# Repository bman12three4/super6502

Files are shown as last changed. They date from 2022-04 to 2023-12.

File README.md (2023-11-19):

# Super6502

## Overview

Super6502 is a microcomputer system powered by a 65C02 CPU. The goal of this
project is to create a computer system with modern features and the ability to
run modern software on an unmodified 65C02 core. While the project is almost
entirely contained in an FPGA, this rule is enforced by using an off the shelf
CPU.

## Goals

There are a few goals that I have for this project.

The number 1 goal is to create a pre-emptive multitasking operating system with
virtual memory.

I also have a few stretch goals:

1. Connect it to the internet

2. Boot linux (lol)

Along the way, there are a few milestones that I want to reach:

* USB support, including mass storage and peripherals
* HDMI Display output
* Ethernet

## Details

Currently, the project is built around an Efinix Trion T20F256 Development board.
I also have a breakout board with an SD card slot, a MAX3421E, and an audio codec
(that I forget the pn) which I got at school. Right now I only use the SD card.

The development board is sparse, but it includes SDRAM and enough headers to add
any other peripherals.

I designed a board to plug into one of the headers which exposes nearly all the pins
of a 65C02 directly to the FPGA, with no external circuitry except for 2 pull-up
resistors.

The heart of the project is `super6502.sv`. This file contains all of the various
parts of the project. It contains a small boot rom, but the rest of the code is
loaded from an SD card. All of the peripherals are also instantiated here, and there
is a block at the top for address decoding. It currently contains a very simple MMU
which allows the CPU access to the full 32MB address space. Other peripherals include
a timer, leds, hardware multiplier and divider, a uart, an spi controller (for the sd
card), an interrupt controller, and the SDRAM controller.

The SDRAM controller is the one supplied by the FPGA manufacturer, efinix, but contained
in a wrapper which adapts the native bus to the 6502 bus.

One aspect of the project that I want to improve on is bus interoperability. There is
a huge world of IP that is available if I support AXI or WishBone, but at the moment
I do not.

## Simulation Effort

Because I mostly work on this project while on the bus going to/from work, I can't be
iteratively testing on the hardware. I was inspired by the simulation setup we have at
work for the Starlink ASICs and decided to try and implement something similar, albeit
with only free tools at my disposal. It mostly works, but is very slow. Booting the
kernel takes nearly an hour(!), and that is with no kernel features or functionality.

For this reason, the IP blocks have standalone simulations as well as full system
simulations

## Contributing

While I appreciate feedback, this my own personal project and I will not accept
external contributions.

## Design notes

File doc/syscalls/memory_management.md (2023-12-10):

# Physical Memory Management

Physical memory will be handled in 4kb chunks. Each of these chunks needs to
be managed somehow.

We need a way for each PID to correspond with a list of memory mappings that
need to be loaded in.

In the ultra simple case. We don't assign memory dynamically and the mappings
are completely dependent on the PID. This is the easy case, allows only for
1022 processes at once.

The physical memory mapping then depends on the PID, where the base address of
any process is $$ (PID + 1) * 65536 $$

For minimum proof of concept, we can roll with this for now.

In the future, I would only like to assign a minimum of 8 blocks to a process,
and any dynamically allocated blocks would come after that.



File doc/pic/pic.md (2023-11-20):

# PIC

## Overview

The PIC (Programmable Interrupt Controller) supports 256 edge or level
triggered interrupts.

Interrupts can only be rising edge or positive level trigger. Negative edge or
low level trigger can be accomplished by inverting the input to this module.

When an interrupt is triggered, it remains triggered until cleared with an
`EOI`. Currently, only the highest priority interrupt can be cleared. This
is bad design and will be fixed soon(tm).

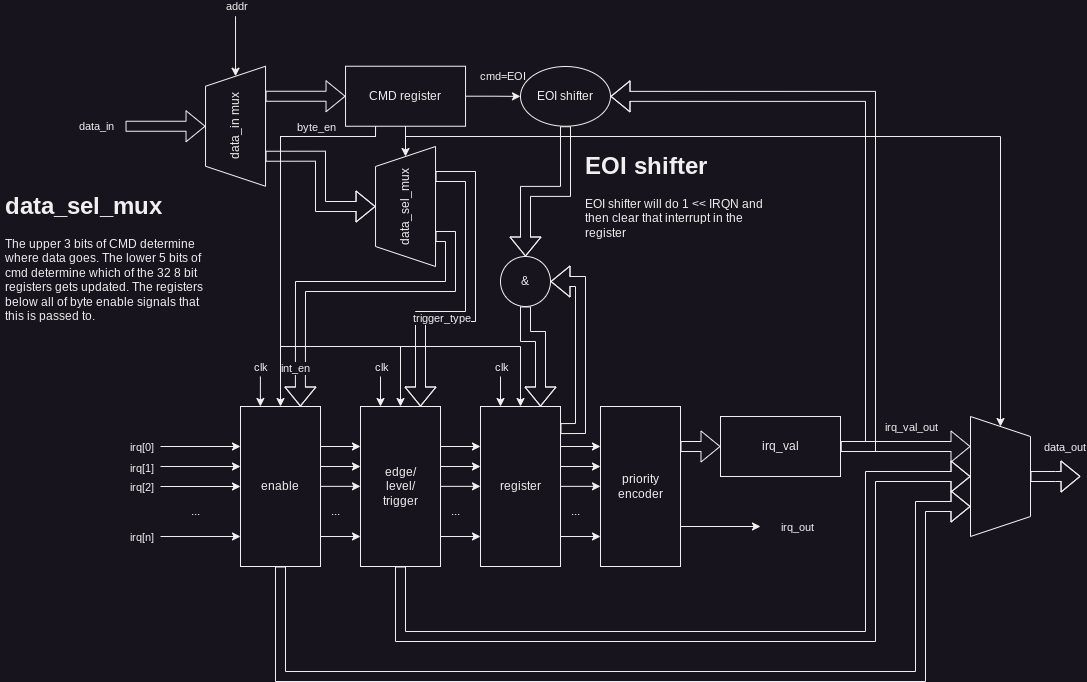
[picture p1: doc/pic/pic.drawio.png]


## Interface

The PIC is controlled through two 8-bit registers, `CMD` and `DAT`.
The upepr 3 bits of `CMD` control which register is accessed, and the lower 5
bits control the byte select.

`EOI` is a special case: when `CMD` is 0xFF, the highest priority interrupt is
cleared.

### CMD
| [7:5] 	| [4:0] 	|
|---	|---	|
| Register Address 	| Byte Select 	|

### DAT
| [7:0]                 	|
|-----------------------	|
| Data[8*Byte_sel +: 8] 	|

## Registers

### Register Map

| Address 	| Read 	| Write  	|
|---	|---	|---	|
| 0 	| IRQ Number 	| ~ 	|
| 1 	| Enable 	| Enable 	|
| 2 	| Type 	| Type 	|

### IRQ Number

8 bit register outputs the highest priority interrupt currently active. When 
no interrupt is active, it will output 255.

### Enable

256 bit enable register. When bit _n_ is set to 1, the corresponding interrupt
_n_.

### Type

256 bit type register. When bit _n_ is set to 0, the corresponding interrupt
_n_ will be edge triggered. If the bit is set to 1, the interrupt will be level
triggered.

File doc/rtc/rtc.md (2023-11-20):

# RTC

## Overview

The RTC is capable of keeping track of elapsed time as well as generating
periodic interrupts. Its input frequency is (currently) the same as the CPU
frequency. The architecture is shown below:

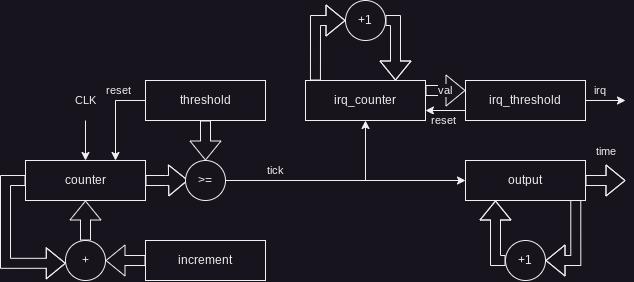
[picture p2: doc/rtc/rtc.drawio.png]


The `counter` register is a 32 bit register which increments by `increment`
every clock tick. When this value reaches `threshold`, both `output` and
`irq_counter` are incremented by 1. When `irq_counter` reaches `irq_threshold`,
an interrupt is generated.

The interrupt frequency can be calculated with the following equations:

$$ F_{out}=\frac{F_{in}\cdot{increment}}{threshold} $$
$$ F_{irq}=\frac{F_{out}}{irq\_threshold} $$

Where $ F_{out} $ is the frequency at which the output changes and $ F_{irq} $
is the frequency at which interrupts occur.

## Interface

The RTC is controlled through two 8-bit registers, `CMD` and `DAT`.
The upepr 4 bits of `CMD` control which register is accessed, and the lower 4
bits control the byte select. The RTC uses 32 bit registers, so only values of
0-3 are supported.

### CMD
| [7:4] 	| [3:2 	| [1:0] 	|
|---	|---	|---	|
| Register Address 	| Reserved 	| Byte Select 	|

### DAT
| [7:0]                 	|
|-----------------------	|
| Data[8*Byte_sel +: 8] 	|

## Registers

### Register Map

| Address 	| Read 	| Write 	|
|---	|---	|---	|
| 0 	| Threshold 	| Threshold 	|
| 1 	| Increment 	| Increment 	|
| 2 	| IRQ Threshold 	| IRQ Threshold 	|
| 3 	| Output 	| Control 	|

### Threshold

32 bit threshold register. When `counter` reaches this value, `output` and
`irq_counter` are incremented by 1, and `counter` is reset back to 0.

### Increment

32 bit increment register. Every clock cycle, `counter` is incremented by
`increment`

### IRQ Threshold

32 bit IRQ threshold register. When `irq_counter` reaches this value, and IRQ
is generated and `irq_counter` is reset back to 0.

### Output

32 bit output register. This value ticks up.

### Control

| [7:2] 	| [1] 	| [0] 	|
|---	|---	|---	|
| Reserved 	| IRQ Enable 	| Enable 	|

8 bit Control register. Regardless of Byte Select, any write to address 3 will
write to this register. `IRQ Enable` controls interrupt generation. `Enable` is
a global enable. When 0, all counter registers are set to 0.

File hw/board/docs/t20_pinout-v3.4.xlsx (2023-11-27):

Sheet: T20F169
© 2020 |  | v23
Bank Number | Pin Names | Configuration Functions | MIPI Channels | LVDS TX/RX Pairs | DDIO | FBGA169
- | GND |  |  |  |  | A1
- | GND |  |  |  |  | A13
- | GND |  |  |  |  | E12
- | GND |  |  |  |  | E2 | Legend
- | GND |  |  |  |  | F5 |  | Bank 1A pins
- | GND |  |  |  |  | F6 |  | Bank 1B pins
- | GND |  |  |  |  | F8 |  | Bank 1C pins
- | GND |  |  |  |  | G6 |  | Bank 1D pins
- | GND |  |  |  |  | G7 |  | Bank 1E pins
- | GND |  |  |  |  | J7 |  | Bank 3A pins
- | GND |  |  |  |  | J8 |  | Bank 3B pins
- | GND |  |  |  |  | K12 |  | Bank 3C pins
- | GND |  |  |  |  | K2 |  | Bank 3D pins
- | GND |  |  |  |  | L12 |  | Bank 3E pins
- | GND |  |  |  |  | M4 |  | Bank 4A pins
- | GND |  |  |  |  | N1 |  | Bank 4B pins
- | GND |  |  |  |  | N13
- | GNDA_MIPI |  |  |  |  | C11
- | GNDA_MIPI |  |  |  |  | D11 | Note: | In the Legend, banks with the same color have their power shorted in the package
- | GNDA_MIPI |  |  |  |  | D3 |  | For example, VCCIO3C_3D_3E shorts the power of bank 3C, 3D and 3E together
- | GNDA_MIPI |  |  |  |  | E5
- | VCC |  |  |  |  | E4
- | VCC |  |  |  |  | F7
- | VCC |  |  |  |  | F9
- | VCC |  |  |  |  | G5
- | VCC |  |  |  |  | G8
- | VCC |  |  |  |  | G9
- | VCC |  |  |  |  | H6
- | VCC |  |  |  |  | J6
- | VCC12A_MIPI0_RX |  |  |  |  | E6
- | VCC12A_MIPI0_TX |  |  |  |  | C3
- | VCC12A_MIPI1_RX |  |  |  |  | E10
- | VCC12A_MIPI1_TX |  |  |  |  | E8
- | VCC25A_MIPI0 |  |  |  |  | E7
- | VCC25A_MIPI1 |  |  |  |  | E9
- | VCCA_BR |  |  |  |  | J10
- | VCCA_TL |  |  |  |  | G4
- | VCCA_TR |  |  |  |  | G10
- | VCCIO1A |  |  |  |  | J4
- | VCCIO1B_1C_1D |  |  |  |  | H4
- | VCCIO1E |  |  |  |  | F4
- | VCCIO3A_3B |  |  |  |  | F10
- | VCCIO3C_3D_3E |  |  |  |  | H10
- | VCCIO4A |  |  |  |  | H7
- | VCCIO4A |  |  |  |  | H8
- | VCCIO4A |  |  |  |  | H9
- | VCCIO4A |  |  |  |  | J9
- | VCCIO4B |  |  |  |  | H5
- | VCCIO4B |  |  |  |  | J5
BANK1A | CDONE | CDONE |  |  |  | L2
BANK1A | CRESET_N | CRESET_N |  |  |  | K3
BANK1A | GPIOL_00_SS_N | SS_N |  |  |  | L1
BANK1A | GPIOL_01_CCK | CCK |  |  |  | K1
BANK1A | GPIOL_08_CDI0 | CDI0 |  |  |  | J1
BANK1A | GPIOL_09_CDI1 | CDI1 |  |  |  | J2
BANK1A | TCK |  |  |  |  | H1
BANK1A | TDI |  |  |  |  | J3
BANK1A | TDO |  |  |  |  | G1
BANK1A | TMS |  |  |  |  | H2
BANK1B | GPIOL_12_CDI2 | CDI2 |  |  | Yes | F1
BANK1B | GPIOL_13_CDI3 | CDI3 |  |  | Yes | G2
BANK1B | GPIOL_20_CTRL0_CDI4 |  |  |  | Yes | E1
BANK1B | GPIOL_21_CTRL1_CDI5 |  |  |  | Yes | F2
BANK1B | GPIOL_24_CLK0 |  |  |  | Yes | H3
BANK1B | GPIOL_25_CLK1 |  |  |  | Yes | G3
BANK1E | GPIOL_69_CBSEL1 | CBSEL1 |  |  |  | D1
BANK1E | GPIOL_70_CBSEL0 | CBSEL0 |  |  |  | D2
BANK1E | GPIOL_71_NSTATUS | NSTATUS |  |  |  | C2
BANK1E | GPIOL_72_EXTFB0_CDI14 |  |  |  |  | F3
BANK1E | GPIOL_73_EXTFB1_CDI15 |  |  |  |  | C1
BANK1E | GPIOL_74_PLLIN0 |  |  |  |  | E3
BANK1E | GPIOL_75_PLLIN1 |  |  |  |  | B1
BANK2A | MIPI0_RXDN0 |  | MIPI_RX0 |  |  | A5
BANK2A | MIPI0_RXDN1 |  | MIPI_RX0 |  |  | D6
BANK2A | MIPI0_RXDN2 |  | MIPI_RX0 |  |  | A6
BANK2A | MIPI0_RXDN3 |  | MIPI_RX0 |  |  | D7
BANK2A | MIPI0_RXDN4 |  | MIPI_RX0 |  |  | A7
BANK2A | MIPI0_RXDP0 |  | MIPI_RX0 |  |  | B5
BANK2A | MIPI0_RXDP1 |  | MIPI_RX0 |  |  | C6
BANK2A | MIPI0_RXDP2 |  | MIPI_RX0 |  |  | B6
BANK2A | MIPI0_RXDP3 |  | MIPI_RX0 |  |  | C7
BANK2A | MIPI0_RXDP4 |  | MIPI_RX0 |  |  | B7
BANK2A | MIPI0_TXDN0 |  | MIPI_TX0 |  |  | B2
BANK2A | MIPI0_TXDN1 |  | MIPI_TX0 |  |  | D4
BANK2A | MIPI0_TXDN2 |  | MIPI_TX0 |  |  | B3
BANK2A | MIPI0_TXDN3 |  | MIPI_TX0 |  |  | D5
BANK2A | MIPI0_TXDN4 |  | MIPI_TX0 |  |  | B4
BANK2A | MIPI0_TXDP0 |  | MIPI_TX0 |  |  | A2
BANK2A | MIPI0_TXDP1 |  | MIPI_TX0 |  |  | C4
BANK2A | MIPI0_TXDP2 |  | MIPI_TX0 |  |  | A3
BANK2A | MIPI0_TXDP3 |  | MIPI_TX0 |  |  | C5
BANK2A | MIPI0_TXDP4 |  | MIPI_TX0 |  |  | A4
BANK2B | MIPI1_RXDN0 |  | MIPI_RX1 |  |  | A11
BANK2B | MIPI1_RXDN1 |  | MIPI_RX1 |  |  | D10
BANK2B | MIPI1_RXDN2 |  | MIPI_RX1 |  |  | A12
BANK2B | MIPI1_RXDN3 |  | MIPI_RX1 |  |  | D12
BANK2B | MIPI1_RXDN4 |  | MIPI_RX1 |  |  | B13
BANK2B | MIPI1_RXDP0 |  | MIPI_RX1 |  |  | B11
BANK2B | MIPI1_RXDP1 |  | MIPI_RX1 |  |  | C10
BANK2B | MIPI1_RXDP2 |  | MIPI_RX1 |  |  | B12
BANK2B | MIPI1_RXDP3 |  | MIPI_RX1 |  |  | C12
BANK2B | MIPI1_RXDP4 |  | MIPI_RX1 |  |  | C13
BANK2B | MIPI1_TXDN0 |  | MIPI_TX1 |  |  | A8
BANK2B | MIPI1_TXDN1 |  | MIPI_TX1 |  |  | D8
BANK2B | MIPI1_TXDN2 |  | MIPI_TX1 |  |  | B9
BANK2B | MIPI1_TXDN3 |  | MIPI_TX1 |  |  | D9
BANK2B | MIPI1_TXDN4 |  | MIPI_TX1 |  |  | B10
BANK2B | MIPI1_TXDP0 |  | MIPI_TX1 |  |  | B8
BANK2B | MIPI1_TXDP1 |  | MIPI_TX1 |  |  | C8
BANK2B | MIPI1_TXDP2 |  | MIPI_TX1 |  |  | A9
BANK2B | MIPI1_TXDP3 |  | MIPI_TX1 |  |  | C9
BANK2B | MIPI1_TXDP4 |  | MIPI_TX1 |  |  | A10
BANK3A | GPIOR_76_PLLIN0 |  |  |  |  | D13
BANK3A | GPIOR_77_PLLIN1 |  |  |  |  | F12
BANK3A | GPIOR_78_EXTFB0_CDI31 |  |  |  |  | E13
BANK3A | GPIOR_81_MREFCLK |  |  |  |  | F11
BANK3A | GPIOR_85 |  |  |  |  | E11
BANK3A | GPIOR_88_CDI28 |  |  |  |  | G11
BANK3C | GPIOR_119_CTRL12 |  |  |  | Yes | F13
BANK3C | GPIOR_120_CLK15 |  |  |  | Yes | G12
BANK3C | GPIOR_121_CLK14 |  |  |  | Yes | H11
BANK3E | GPIOR_150_CBUS1 | CBUS1 |  |  | Yes | G13
BANK3E | GPIOR_151_CBUS0 | CBUS0 |  |  | Yes | J11
BANK3E | GPIOR_155 |  |  |  | Yes | H13
BANK3E | GPIOR_157_PLLIN |  |  |  | Yes | J12
BANK3E | GPIOR_158_TEST_N | TEST_N |  |  | Yes | H12
BANK4A | GPIOB_CLKN0 |  |  | GPIOB_CLK0 |  | L13
BANK4A | GPIOB_CLKP0 |  |  | GPIOB_CLK0 |  | M13
BANK4A | GPIOB_RXN00 |  |  | GPIOB_RX00 |  | K7
BANK4A | GPIOB_RXN01 |  |  | GPIOB_RX01 |  | M7
BANK4A | GPIOB_RXN02 |  |  | GPIOB_RX02 |  | K8
BANK4A | GPIOB_RXN03 |  |  | GPIOB_RX03 |  | N8
BANK4A | GPIOB_RXN04 |  |  | GPIOB_RX04 |  | L9
BANK4A | GPIOB_RXN05 |  |  | GPIOB_RX05 |  | N9
BANK4A | GPIOB_RXN06 |  |  | GPIOB_RX06 |  | L10
BANK4A | GPIOB_RXN07 |  |  | GPIOB_RX07 |  | M10
BANK4A | GPIOB_RXN08 |  |  | GPIOB_RX08 |  | L11
BANK4A | GPIOB_RXN09 |  |  | GPIOB_RX09 |  | M12
BANK4A | GPIOB_RXN10 |  |  | GPIOB_RX10 |  | N12
BANK4A | GPIOB_RXN12_EXTFB0 |  |  | GPIOB_RX12 |  | K13
BANK4A | GPIOB_RXP00 |  |  | GPIOB_RX00 |  | L7
BANK4A | GPIOB_RXP01 |  |  | GPIOB_RX01 |  | N7
BANK4A | GPIOB_RXP02 |  |  | GPIOB_RX02 |  | L8
BANK4A | GPIOB_RXP03 |  |  | GPIOB_RX03 |  | M8
BANK4A | GPIOB_RXP04 |  |  | GPIOB_RX04 |  | K9
BANK4A | GPIOB_RXP05 |  |  | GPIOB_RX05 |  | M9
BANK4A | GPIOB_RXP06 |  |  | GPIOB_RX06 |  | K10
BANK4A | GPIOB_RXP07 |  |  | GPIOB_RX07 |  | N10
BANK4A | GPIOB_RXP08 |  |  | GPIOB_RX08 |  | K11
BANK4A | GPIOB_RXP09 |  |  | GPIOB_RX09 |  | M11
BANK4A | GPIOB_RXP10 |  |  | GPIOB_RX10 |  | N11
BANK4A | GPIOB_RXP12_EXTFB0 |  |  | GPIOB_RX12 |  | J13
BANK4B | GPIOB_TXN00 |  |  | GPIOB_TX00 |  | N2
BANK4B | GPIOB_TXN01 |  |  | GPIOB_TX01 |  | M1
BANK4B | GPIOB_TXN02 |  |  | GPIOB_TX02 |  | L3
BANK4B | GPIOB_TXN03 |  |  | GPIOB_TX03 |  | L4
BANK4B | GPIOB_TXN05 |  |  | GPIOB_TX05 |  | M5
BANK4B | GPIOB_TXN06 |  |  | GPIOB_TX06 |  | L5
BANK4B | GPIOB_TXN08 |  |  | GPIOB_TX08 |  | M6
BANK4B | GPIOB_TXN09 |  |  | GPIOB_TX09 |  | L6
BANK4B | GPIOB_TXP00 |  |  | GPIOB_TX00 |  | N3
BANK4B | GPIOB_TXP01 |  |  | GPIOB_TX01 |  | M2
BANK4B | GPIOB_TXP02 |  |  | GPIOB_TX02 |  | M3
BANK4B | GPIOB_TXP03 |  |  | GPIOB_TX03 |  | K4
BANK4B | GPIOB_TXP05 |  |  | GPIOB_TX05 |  | N5
BANK4B | GPIOB_TXP06 |  |  | GPIOB_TX06 |  | K5
BANK4B | GPIOB_TXP08 |  |  | GPIOB_TX08 |  | N6
BANK4B | GPIOB_TXP09 |  |  | GPIOB_TX09 |  | K6
BANK4B | REF_RES |  |  |  |  | N4
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

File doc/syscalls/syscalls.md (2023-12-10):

# Syscalls and Process Creation

## Creating a Process

This is a little bit simpler than on x86 since we don't have to worry about 
process rings and such.

1. Remap the program address space to somewhere new in memory
2. Load the o65 file into memory
3. Remap page zero
4. Jump into starting address of program

We also need to save address of the instruction after the jump. If I am not 
mistaken then this would always be the same anyway. Regardless, we can get
this address by using `jsr` if we want it to be dynamic.

The hardware and software stacks are hardcoded, but we can remap page zero
into a different page (say, page 1) to make the changes to the stack pointers
and such, and then only remap it right before we jump in.

Unfortunately this means we won't be able to use a funtion call for this
since the return address would not be where we expect it.

A more detailed process then:

1. Determine the new processes PID. This will be used to determine the addresses
for where the main memory is mapped.

2. Map An area of ram for page zero. Here will will initialize the kernel
and user stack pointers, as well as place the Process Control Block.

3. Map the main program area into memory and copy data into it

4. Get the return address of the program, which is the address of the 
instruction following the `jmp`. 

5. Remap page zero

6. Immediately after that (like, the very next instruction) `jmp` to the start
of the user program. (We don't use `jsr` because that will save to the wrong
stack).

## Ending A Process

To end a process, we remap the parent processes memory, then jump back to the
address before the `jmp`, as noted before.

## Syscalls

Syscalls require the following:

1. Enter kernel space through use of software interrupt (`brk`)

2. Map in the kernel memory. The kernel is too large to always be mapped, so
we unmap it when we enter user space and remap it when we enter kernel space.

3. Jump to the specific syscall routine in the kernel and do whatever it does

4. Remap the current process memory

5. Jump back into userspace.

A note on 2: While we can't have the entire kernel mapped at all times, we must
have at least part of it so that we can handle interrupts and memory remapping.

This will be the top page in the virtual address space, aka 0xF000 to 0xFFFF.
This must be mapped anyway because it is where the hardware interrupt vectors
are located.

One thing to note about this is that the cc65 runtime will most likely not be
located there, nor do we really want it to be. Because of this, we will not
be able to have any C code, not will we be able to use the runtime in
assembly.

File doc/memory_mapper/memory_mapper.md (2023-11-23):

# Memory Mapper

## Overview

The memory mapper gives expands the CPU's address space from 16 bits to 25.
It can be expanded to be 28 bits, but only 25 are needed to access all of
sdram.

Its architecture is show below:

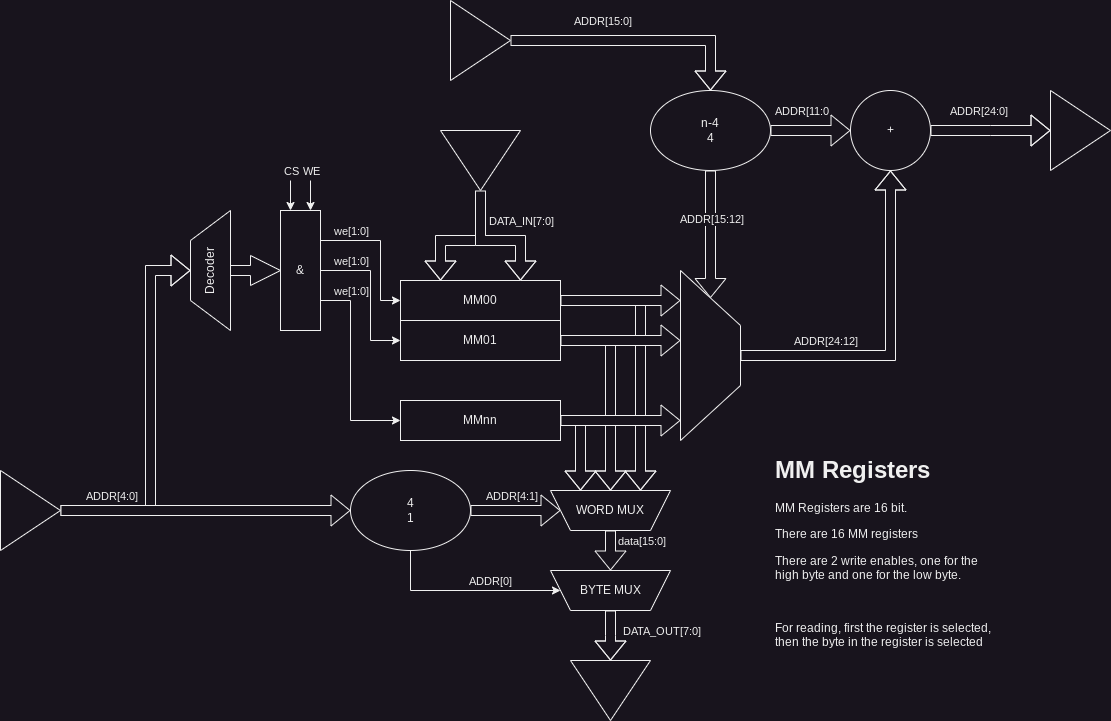
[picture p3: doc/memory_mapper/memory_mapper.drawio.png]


There are 32 16 bit registers: One for each 4k page in the virtual address
space. The memory mapper is always enabled, but at reset it is identity
mapped, i.e. register _n_ will be reset to value _n_.

## Interface

The Memory mapper is composed of 32 identical 16 bit mapping registers

The chip select should be calculated based on the virtual address. If not,
it will be possible for the CPU to map away access to the mapper, at which
point it is impossible to change the mappings without a reset.

## Registers

### Register Map

| Address 	| Read 	 | Write 	|
|---	|--- |---	|
| 00 	| MM0 Low 	| MM0 Low |
| 01 	| MM0 High  	| MM0 High |
| 02 	| MM1 Low 	| MM1 Low |
| 03 	| MM1 High  	| MM1 High |
| 04 	| MM2 Low 	| MM2 Low |
| 05 	| MM2 High  	| MM2 High |
| 06 	| MM3 Low 	| MM3 Low |
| 07 	| MM3 High  	| MM3 High |
| 08 	| MM4 Low 	| MM4 Low |
| 09 	| MM4 High  	| MM4 High |
| 0A 	| MM5 Low 	| MM5 Low |
| 0B 	| MM5 High  	| MM5 High |
| 0C 	| MM6 Low 	| MM6 Low |
| 0D 	| MM6 High  	| MM6 High |
| 0E 	| MM7 Low 	| MM7 Low |
| 0F 	| MM7 High  	| MM7 High |
| 10 	| MM8 Low 	| MM8 Low |
| 11 	| MM8 High  	| MM8 High |
| 12 	| MM9 Low 	| MM9 Low |
| 13 	| MM9 High  	| MM9 High |
| 14 	| MM10 Low  	| MM10 Low |
| 15 	| MM10 High 	| MM10 High |
| 16 	| MM11 Low  	| MM11 Low |
| 17 	| MM11 High 	| MM11 High |
| 18 	| MM12 Low  	| MM12 Low |
| 19 	| MM12 High 	| MM12 High |
| 1A 	| MM13 Low  	| MM13 Low |
| 1B 	| MM13 High 	| MM13 High |
| 1C 	| MM14 Low  	| MM14 Low |
| 1D 	| MM14 High 	| MM14 High |
| 1E 	| MM15 Low  	| MM15 Low |
| 1F 	| MM15 High 	| MM15 High |

### MMn Low

Low memory map data. Becomes bits [19:12] of physical address.

### MMn High

High memory map data. Becomes bits [27:20] of physical address.

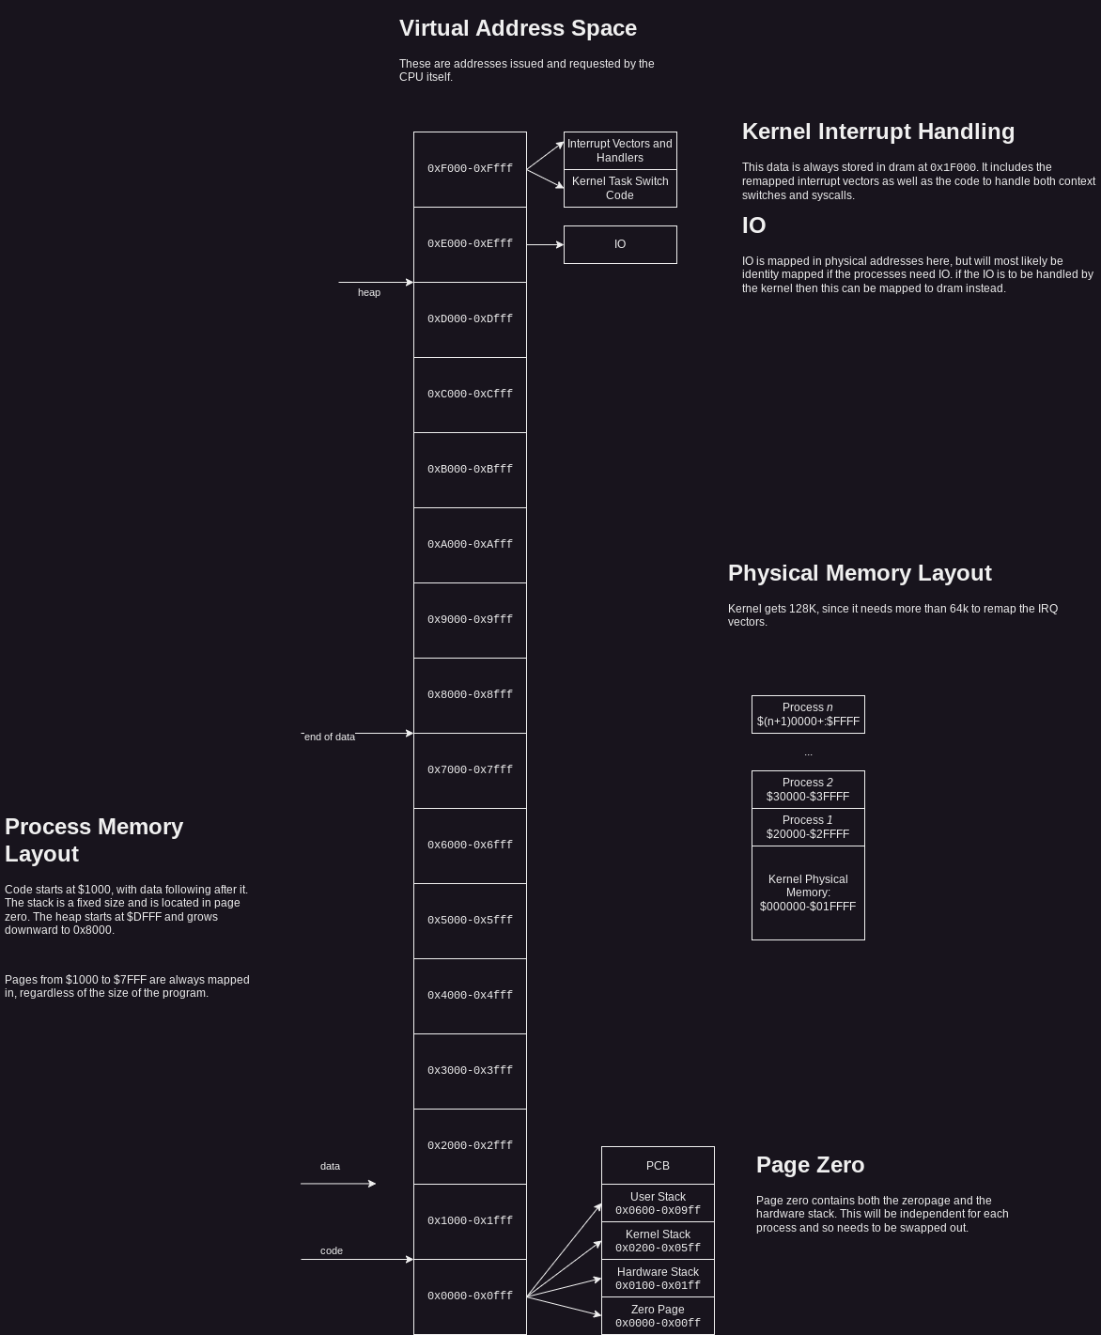
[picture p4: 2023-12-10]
doc/syscalls/Process_Layout.drawio.png

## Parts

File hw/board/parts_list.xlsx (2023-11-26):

Name | Part No | Price | Qty | Total | link | Note
FPGA | T20F400I4 | $26.96 | 1 | $26.96 | https://www.digikey.com/en/products/detail/efinix-inc/T20F400I4/15861249
DDR3L DRAM | MT41K256M8DA-125:K | $5.27 | 1 | $5.27 | https://www.digikey.com/en/products/detail/micron-technology-inc/MT41K256M8DA-125-K/3924859
SPI Flash | MX25V8035FM1I | $0.52 | 1 | $0.52 | https://www.digikey.com/en/products/detail/macronix/MX25V8035FM1I/5957748
MicroSD Card Slot | 5033981892 | $2.73 | 1 | $2.73 | https://www.digikey.com/en/products/detail/molex/5033981892/4555393
FTDI Adapter | FT4232HL-REEL | $6.35 | 1 | $6.35 | https://www.digikey.com/en/products/detail/ftdi-future-technology-devices-international-ltd/FT4232HL-REEL/1986055
USB C Connector | USB4085-GF-A | $0.94 | 1 | $0.94 | https://www.digikey.com/en/products/detail/gct/USB4085-GF-A/9859662
USB Host Controller | MAX3421EEHJ+ | $16.25 | 1 | $16.25 | https://www.digikey.com/en/products/detail/analog-devices-inc-maxim-integrated/MAX3421EEHJ/1464975
USB Hub | TUSB2046BVFR | $3.59 | 1 | $3.59 | https://www.digikey.com/en/products/detail/texas-instruments/TUSB2046BVFR/1910075
USB A Ports | 672984091 | $1.53 | 2 | $3.06 | https://www.digikey.com/en/products/detail/molex/0672984091/3598505
Ethernet PHY | KSZ8081MLXCA-TR | $1.64 | 1 | $1.64 | https://www.digikey.com/en/products/detail/microchip-technology/KSZ8081MLXCA-TR/3879220
Ethernet Jack | SI-50170-F | $5.38 | 1 | $5.38 | https://www.digikey.com/en/products/detail/bel-fuse-inc/SI-50170-F/1033369
HDMI Port | 10029449-111RLF | $1.26 | 1 | $1.26 | https://www.digikey.com/en/products/detail/amphenol-cs-fci/10029449-111RLF/2785386
VGA Port | ICD15S13E6GV00LF | $2.64 | 1 | $2.64 | https://www.digikey.com/en/products/detail/amphenol-cs-fci/ICD15S13E6GV00LF/1090326
6502 CPU | W65C02S6TPG-14 | $9.70 | 1 | $9.70 | https://www.mouser.com/ProductDetail/Western-Design-Center-WDC/W65C02S6TPG-14?qs=opBjA1TV903lvWo9AEKH5w%3D%3D | (Mouser but I already have some)
Green LED | LTST-C191KGKT | $0.06 | 100 | $6.30 | https://www.digikey.com/en/products/detail/liteon/LTST-C191KGKT/386835
3 Switch | 219-3MSTR | $0.69 | 1 | $0.69 | https://www.digikey.com/en/products/detail/cts-electrocomponents/219-3MSTR/5224026
8 Switch | 208-8 | $0.73 | 1 | $0.73 | https://www.digikey.com/en/products/detail/cts-electrocomponents/208-8/20795
Pushbutton | 1825910-6 | $0.13 | 4 | $0.52 | https://www.digikey.com/en/products/detail/te-connectivity-alcoswitch-switches/1825910-6/1632536
7 Segment | LTS-4802BJR-H1 | $1.28 | 6 | $7.68 | https://www.digikey.com/en/products/detail/liteon/LTS-4802BJR-H1/408200
Switching Regulator | ST1S40IDR | $2.18 | 4 | $8.72 | https://www.digikey.com/en/products/detail/stmicroelectronics/ST1S40IDR/3087736
Linear Regulator | ADP123AUJZ-R7 | $1.57 | 1 | $1.57 | https://www.digikey.com/en/products/detail/analog-devices-inc/ADP123AUJZ-R7/2237673
 |  |  |  | $112.50

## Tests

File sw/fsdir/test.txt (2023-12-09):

This is a text file, which is composed of text.

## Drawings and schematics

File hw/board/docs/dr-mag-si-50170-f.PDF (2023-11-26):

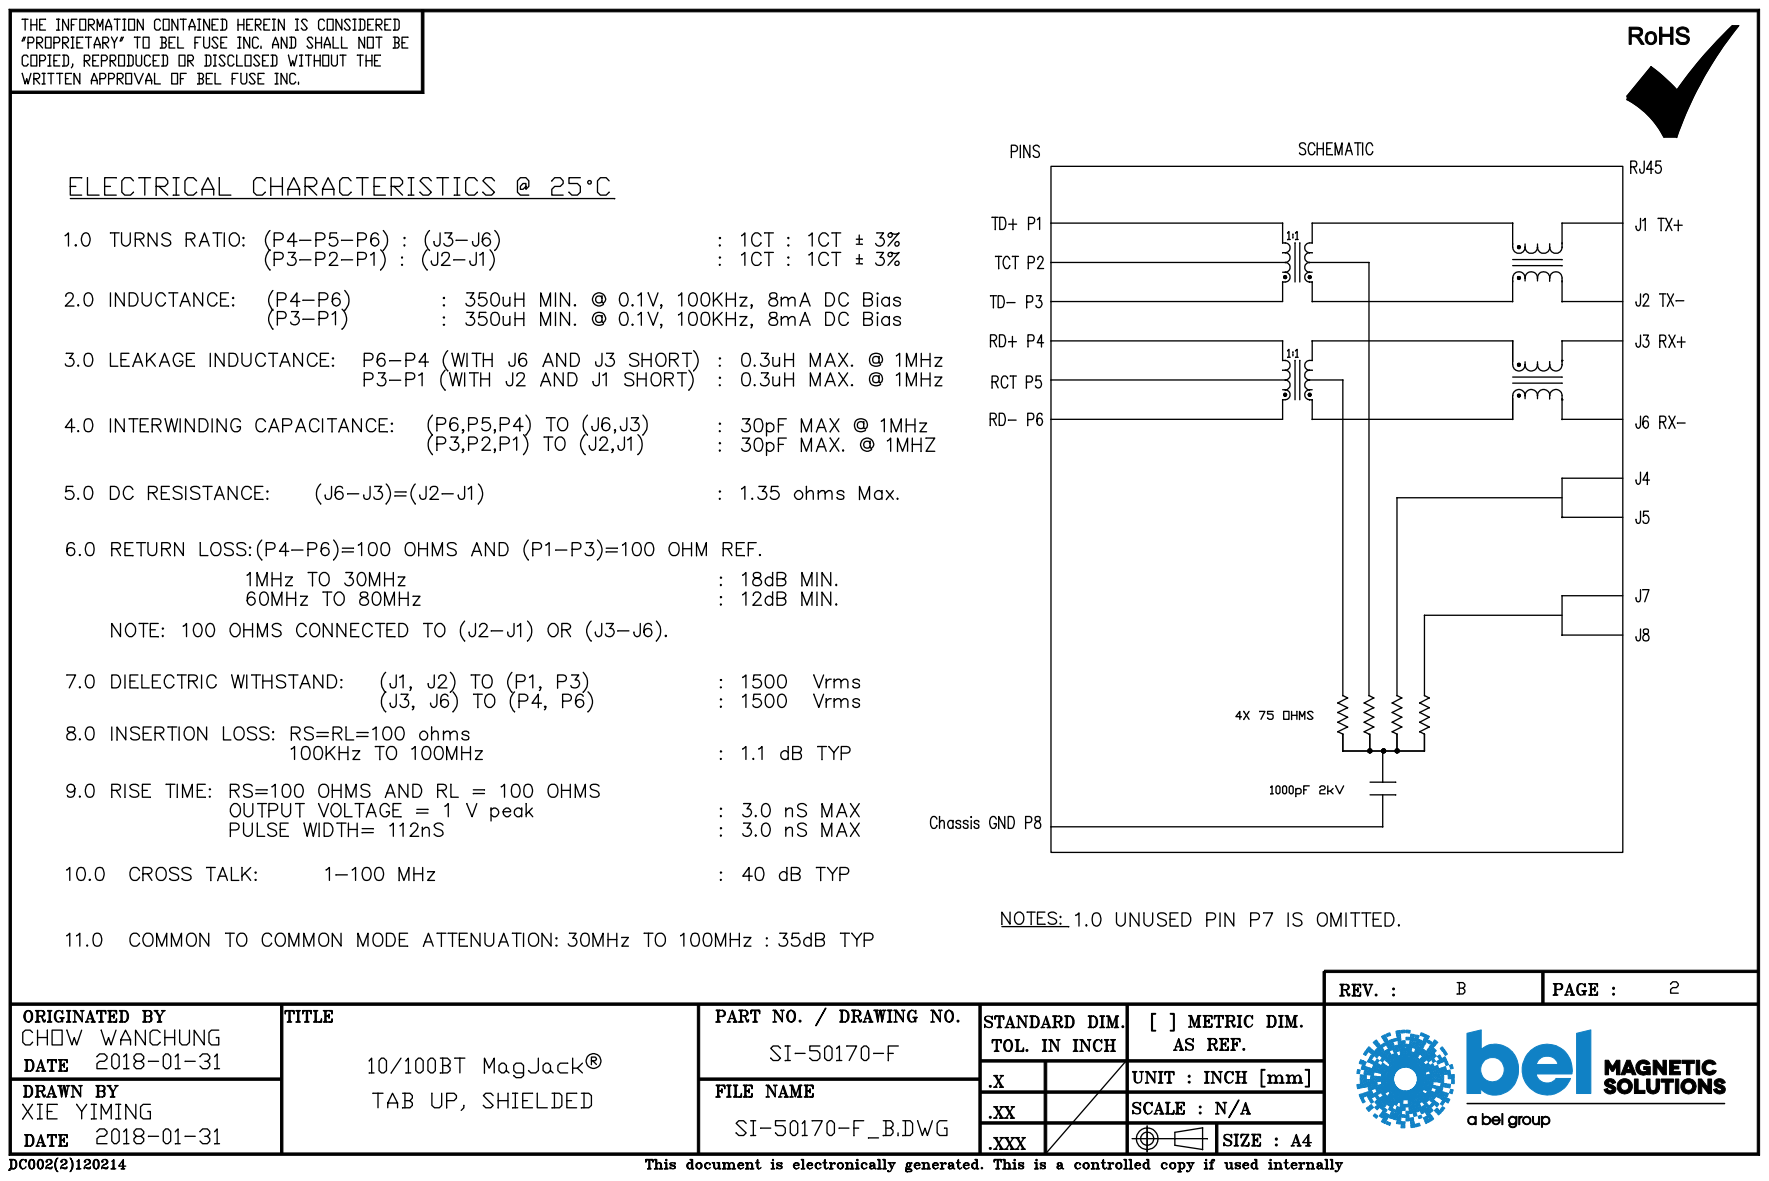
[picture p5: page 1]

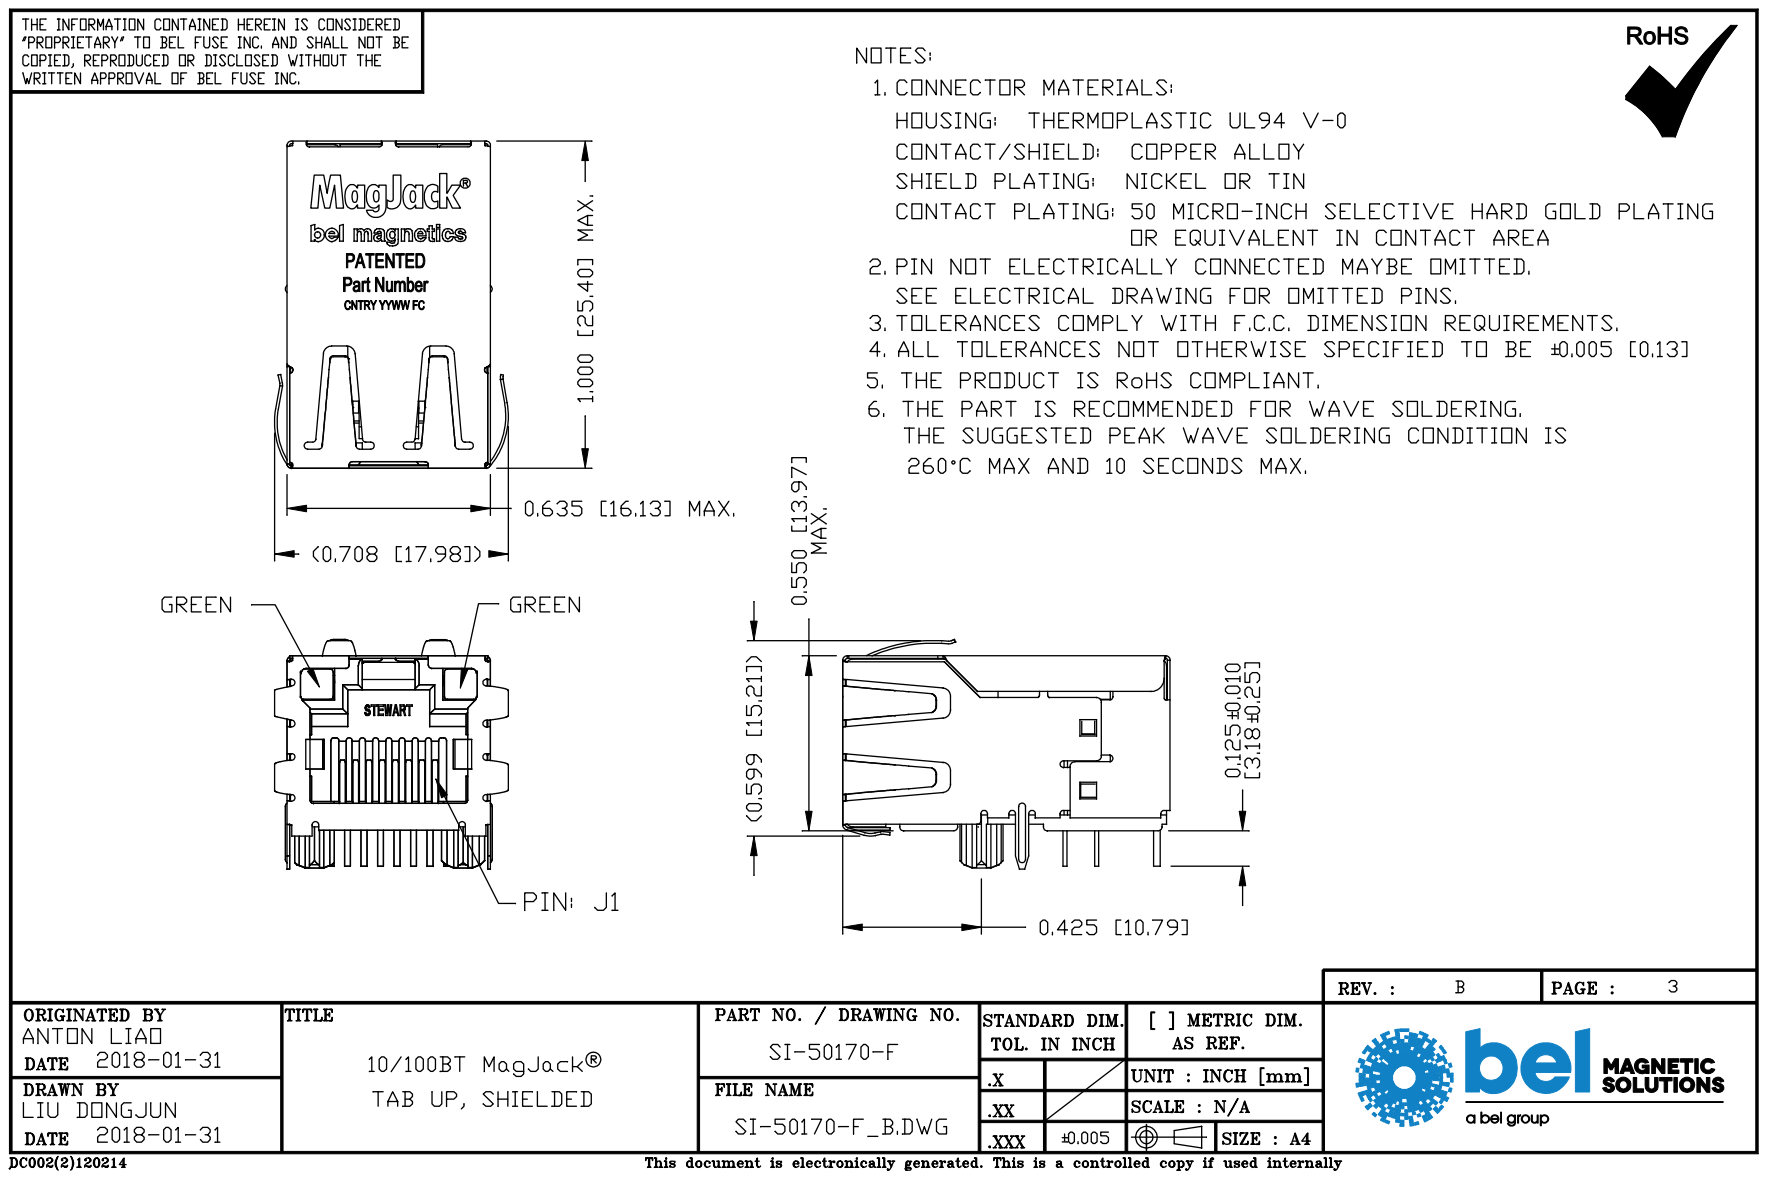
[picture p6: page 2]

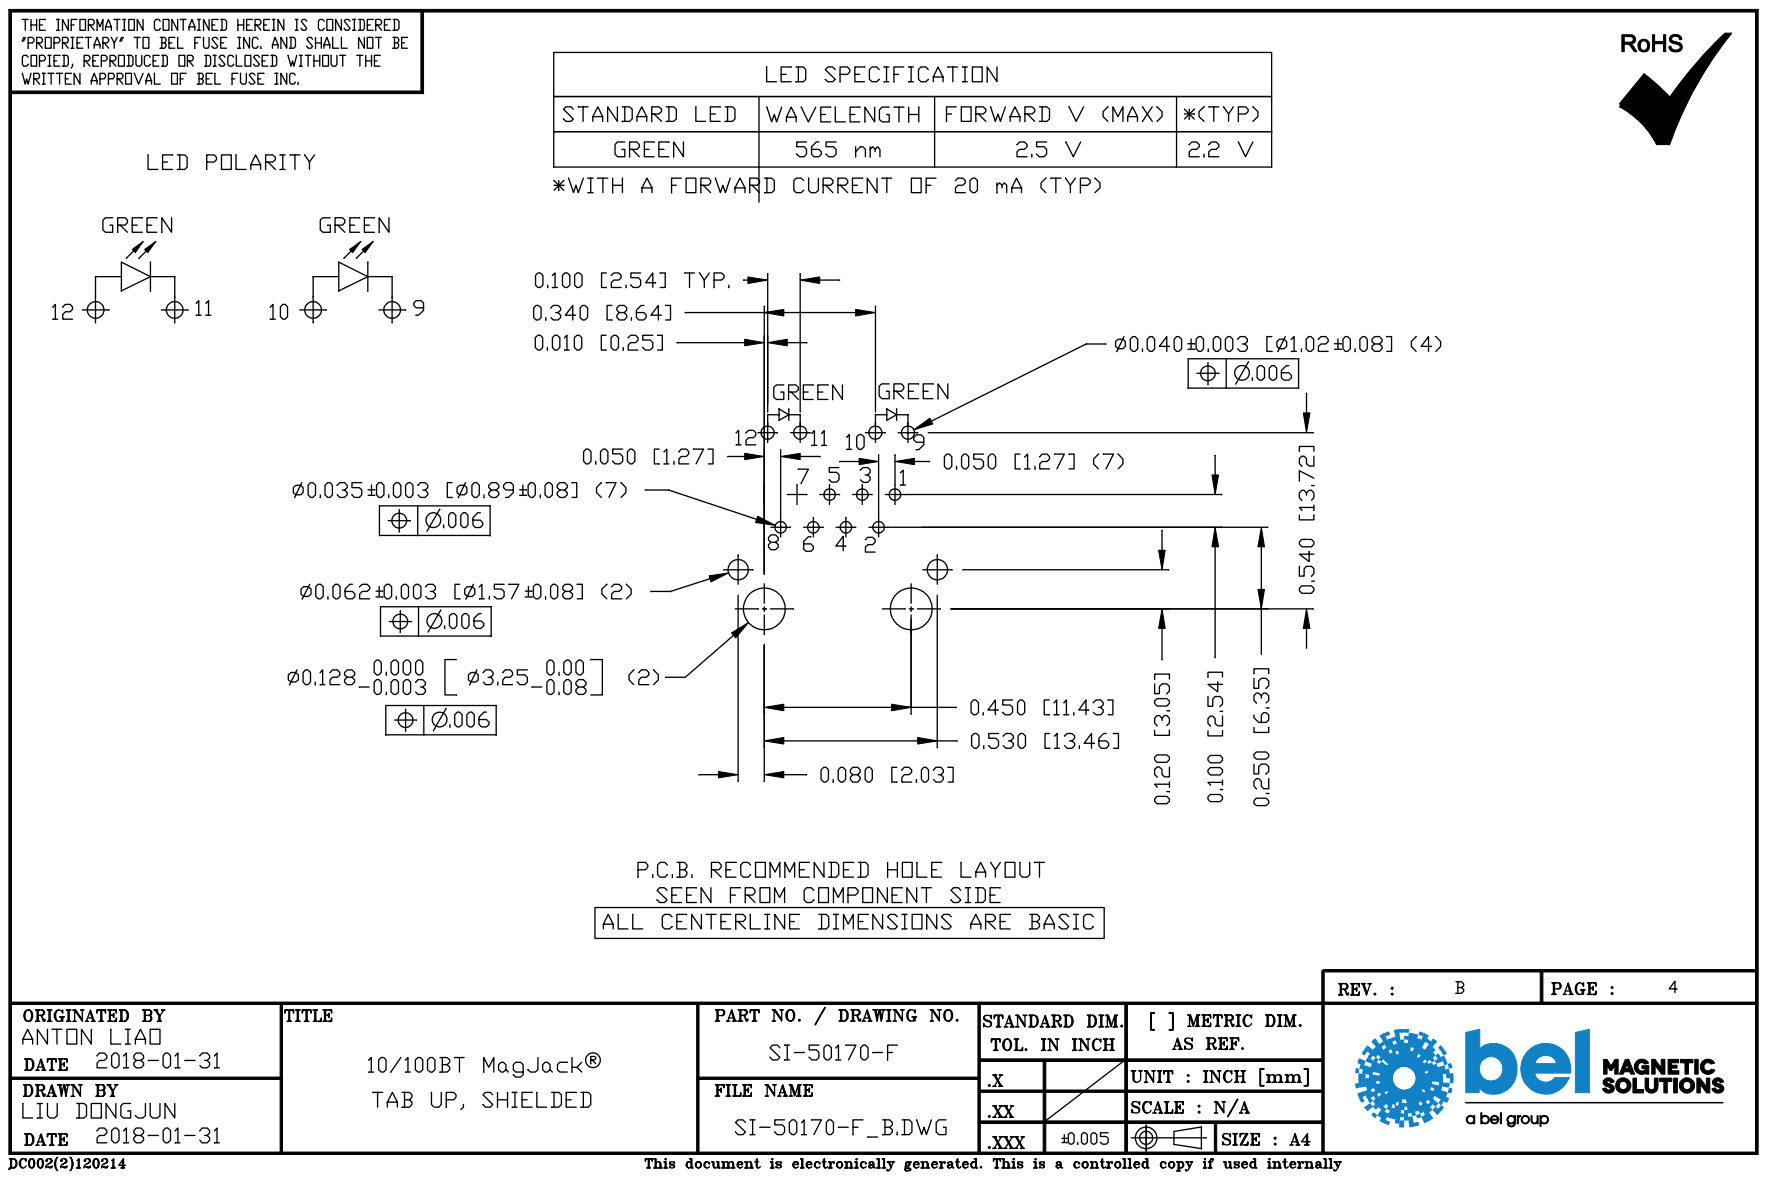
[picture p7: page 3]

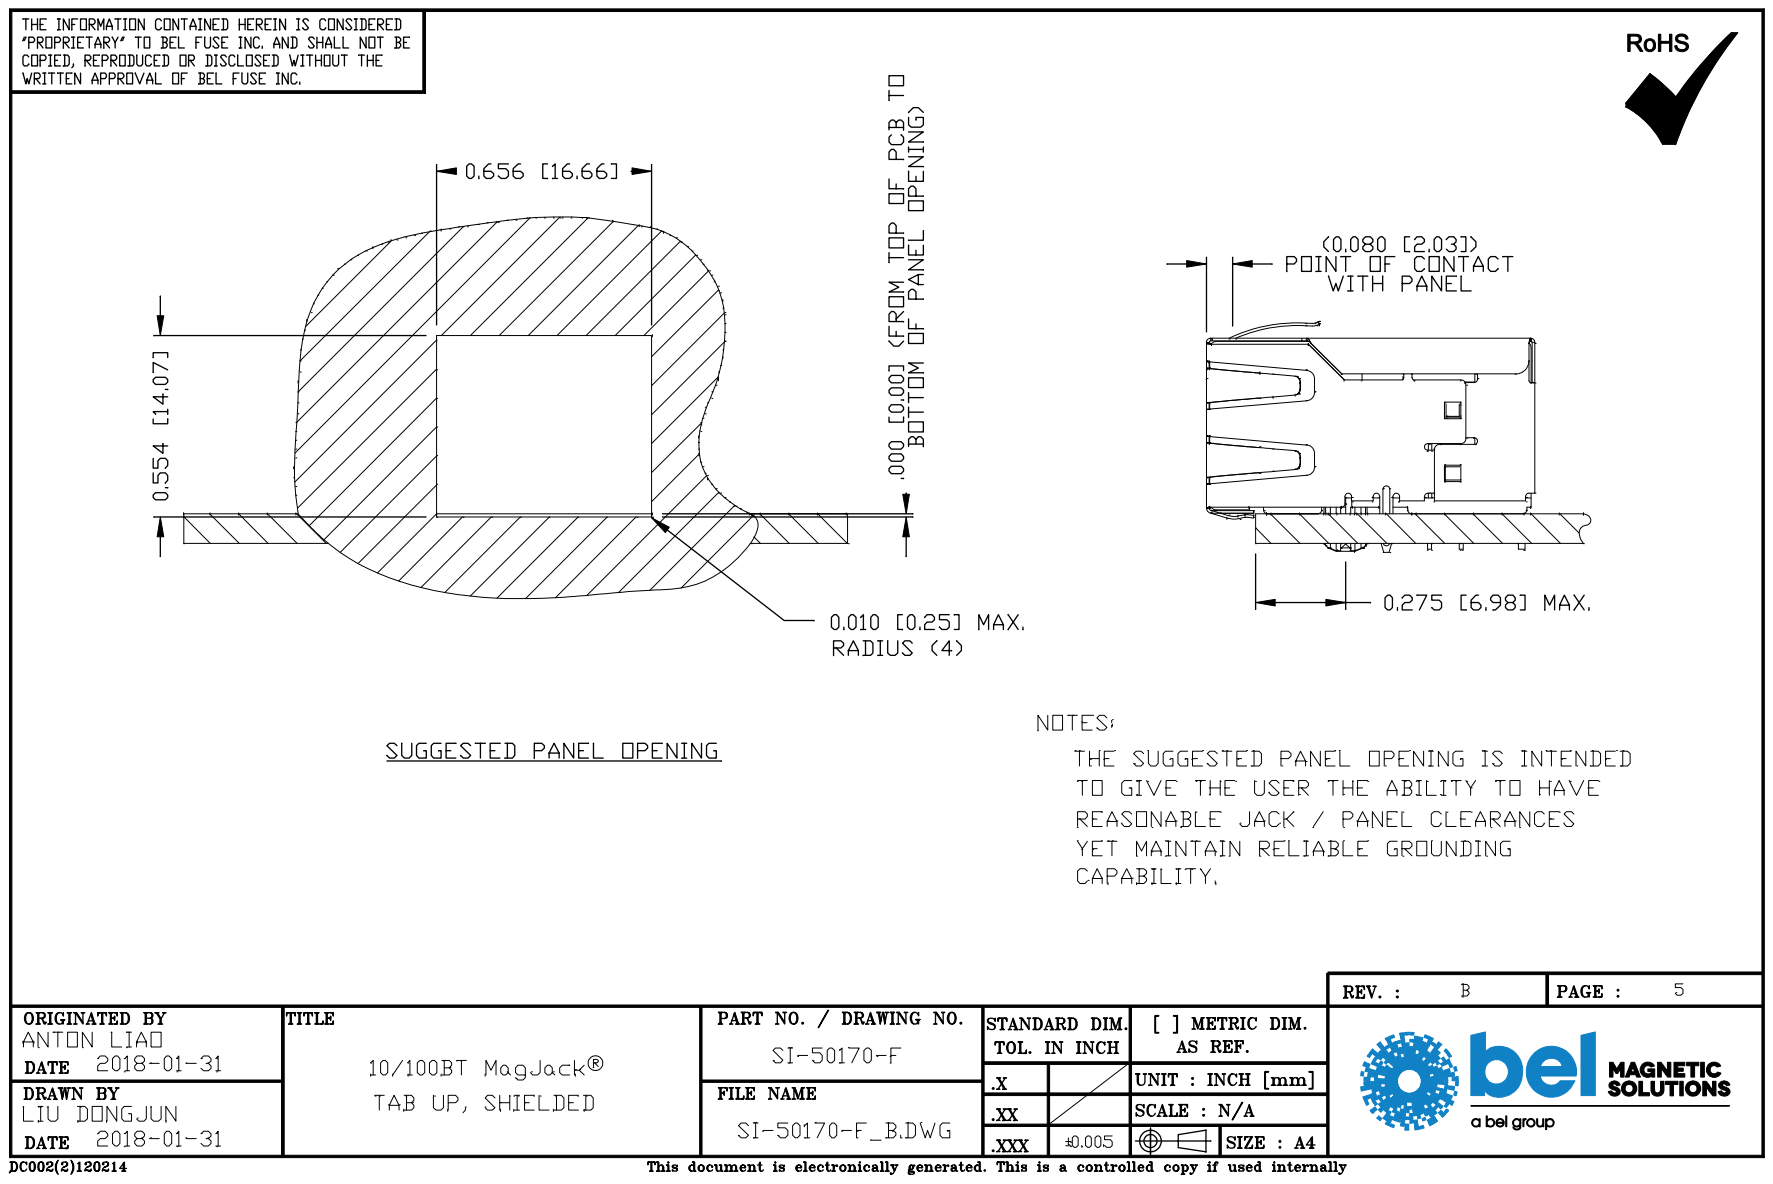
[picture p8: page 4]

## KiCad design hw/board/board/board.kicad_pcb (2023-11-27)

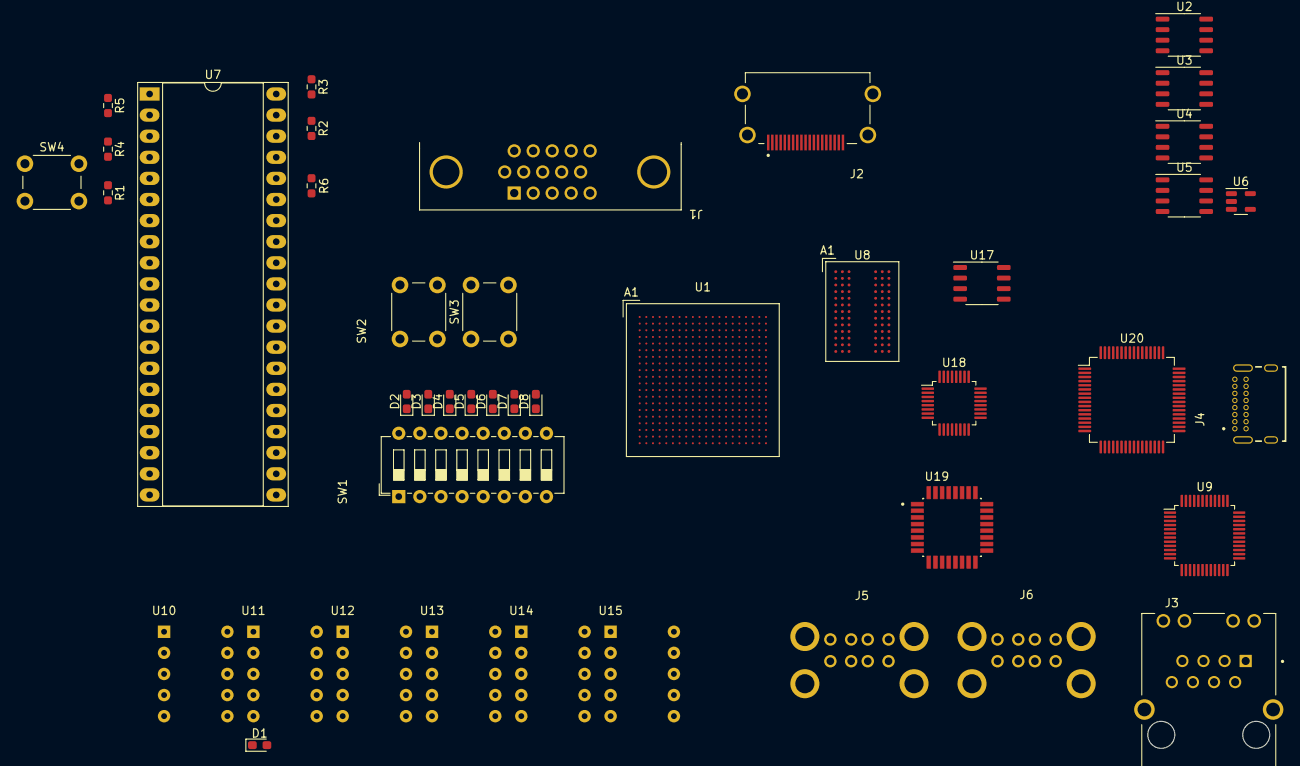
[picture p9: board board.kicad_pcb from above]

Board: 2 copper layers, 43 parts (0 on the bottom side), 8 nets, no tracks yet.

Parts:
D1, D2, D3, D4, D5, D6, D7, D8: LED; LED_0603_1608Metric_Pad1.05x0.95mm_HandSolder
J1: DB15_Female_HighDensity_MountingHoles; ICD15S13E4GX00LF
J2: 10029449-111RLF; AMPHENOL_10029449-111RLF
J3: SI-50170-F; BEL_SI-50170-F
J4: USB4085-GF-A_REVB; GCT_USB4085-GF-A_REVB
J5, J6: USB_A_Stacked; 0672984091
R1, R2, R3, R4, R5, R6: 10K; R_0603_1608Metric_Pad0.98x0.95mm_HandSolder
SW1: SW_DIP_x08; SW_DIP_SPSTx08_Slide_6.7x21.88mm_W7.62mm_P2.54mm_LowProfile
SW2, SW3, SW4: SW_Push; SW_PUSH_6mm_H5mm
U1: BGA-400_17.0x17.0mm_Layout20x20_P0.8mm
U2, U3, U4, U5, U17: SOP-8_3.9x4.9mm_P1.27mm
U6: TSOT-23-5
U7: W65C02P; DIP-40_W15.24mm_Socket_LongPads
U8: BGA-78_8.0x10.5mm_Layout9x12_P0.8mm
U9: LQFP-48_7x7mm_P0.5mm
U10, U11, U12, U13, U14, U15: LTS-4802B
U18: MAX3421E; LQFP-32_5x5mm_P0.5mm
U19: TUSB2046BVFR; QFP80P900X900X160-32N
U20: FT4232H; LQFP-64_10x10mm_P0.5mm

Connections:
+3V3: R1.1, R2.1, R3.1, R4.1, R5.1, R6.1, U7.8 (VDD)
/cpu/CPU_BE: R6.2, U7.36 (BE)
/cpu/CPU_RDY: R5.2, U7.2 (RDY)
/cpu/~CPU_IRQB: R4.2, U7.4 (~IRQB)
/cpu/~CPU_NMIB: R1.2, SW4.2, U7.6 (~NMIB)
/cpu/~CPU_RESB: R3.2, U7.40 (~RESB)
GND: SW4.1, U7.21 (VSS)
unnamed: R2.2, U7.38 (~SOB)

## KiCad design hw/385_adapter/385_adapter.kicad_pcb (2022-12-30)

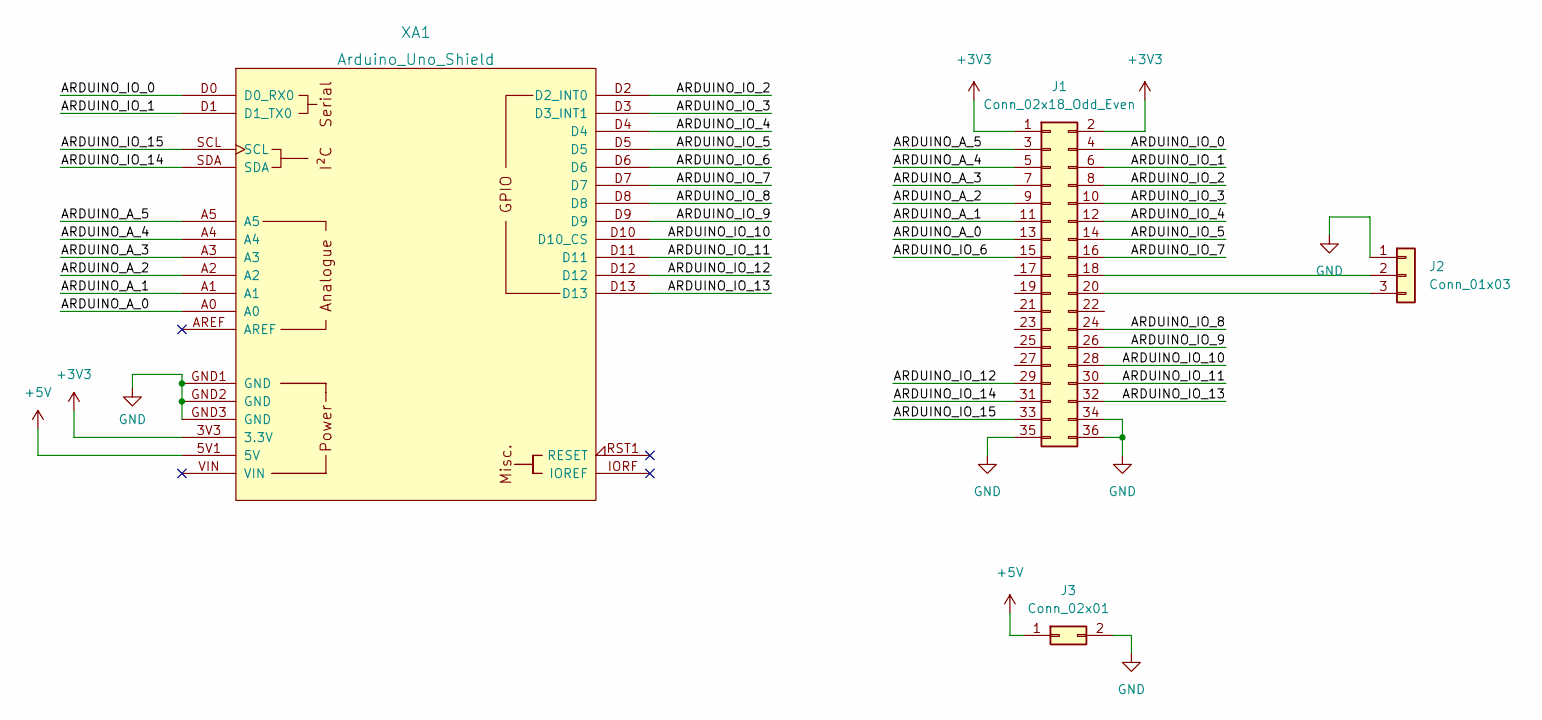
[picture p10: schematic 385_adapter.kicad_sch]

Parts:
J1: Conn_02x18_Odd_Even; PinSocket_2x18_P2.54mm_Vertical
J2: Conn_01x03; PinSocket_1x03_P2.54mm_Vertical
J3: Conn_02x01; PinSocket_2x01_P2.54mm_Vertical
XA1: Arduino_Uno_Shield

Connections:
+3V3: J1.1, J1.2, XA1.3V3 (3.3V)
+5V: J3.1, XA1.5V1 (5V)
/ARDUINO_A_0: J1.13, XA1.A0
/ARDUINO_A_1: J1.11, XA1.A1
/ARDUINO_A_2: J1.9, XA1.A2
/ARDUINO_A_3: J1.7, XA1.A3
/ARDUINO_A_4: J1.5, XA1.A4
/ARDUINO_A_5: J1.3, XA1.A5
/ARDUINO_IO_0: J1.4, XA1.D0 (D0_RX0)
/ARDUINO_IO_1: J1.6, XA1.D1 (D1_TX0)
/ARDUINO_IO_2: J1.8, XA1.D2 (D2_INT0)
/ARDUINO_IO_3: J1.10, XA1.D3 (D3_INT1)
/ARDUINO_IO_4: J1.12, XA1.D4
/ARDUINO_IO_5: J1.14, XA1.D5
/ARDUINO_IO_6: J1.15, XA1.D6
/ARDUINO_IO_7: J1.16, XA1.D7
/ARDUINO_IO_8: J1.24, XA1.D8
/ARDUINO_IO_9: J1.26, XA1.D9
/ARDUINO_IO_10: J1.28, XA1.D10 (D10_CS)
/ARDUINO_IO_11: J1.30, XA1.D11
/ARDUINO_IO_12: J1.29, XA1.D12
/ARDUINO_IO_13: J1.32, XA1.D13
/ARDUINO_IO_14: J1.31, XA1.SDA
/ARDUINO_IO_15: J1.33, XA1.SCL
GND: J1.34, J1.35, J1.36, J2.1, J3.2, XA1.GND1 (GND), XA1.GND2 (GND), XA1.GND3 (GND)
unnamed: J1.18, J2.2
unnamed: J1.20, J2.3

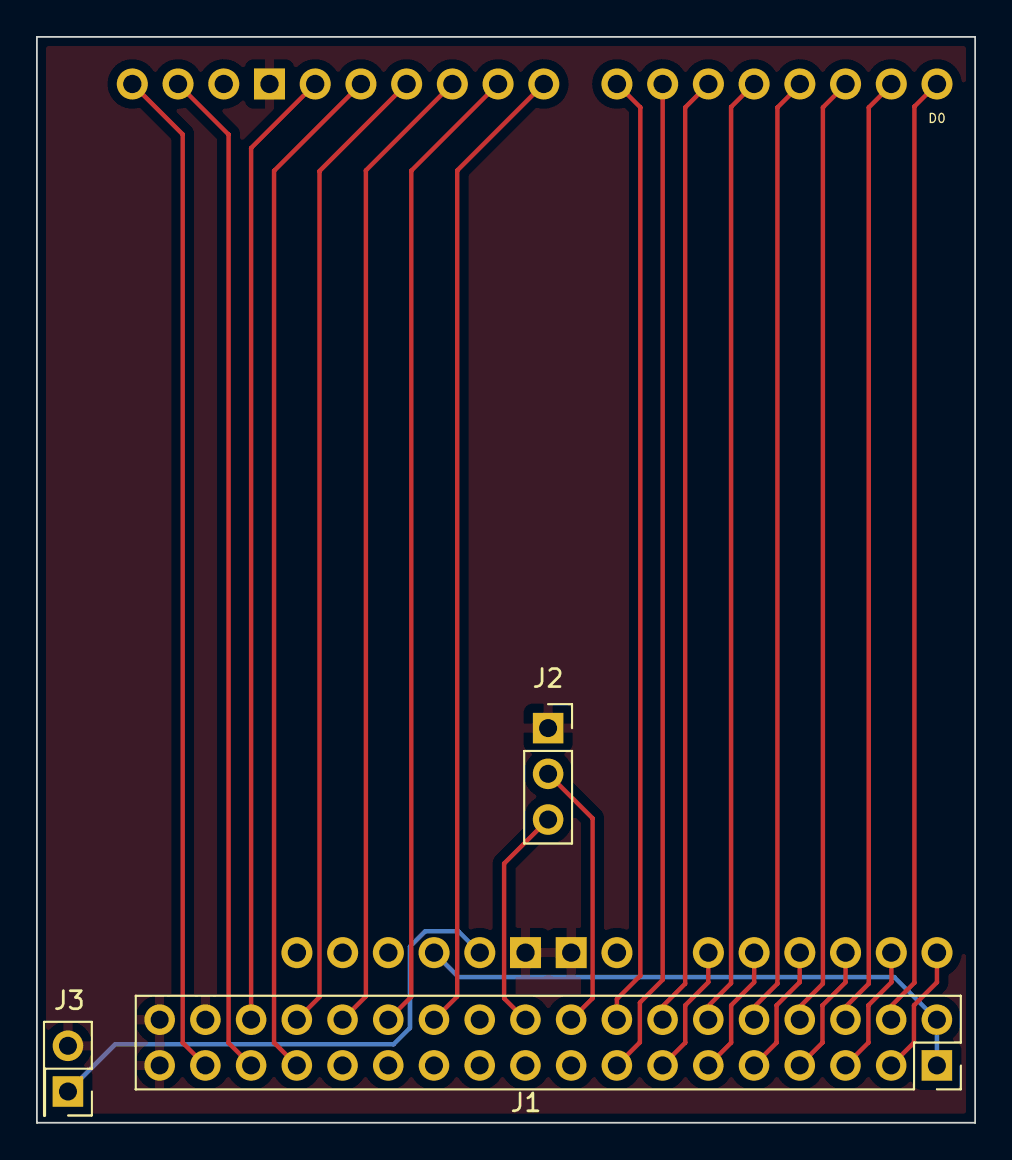
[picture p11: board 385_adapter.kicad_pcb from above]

Board: 2 copper layers, 52.1 x 60.3 mm, 4 parts (0 on the bottom side), 27 nets.

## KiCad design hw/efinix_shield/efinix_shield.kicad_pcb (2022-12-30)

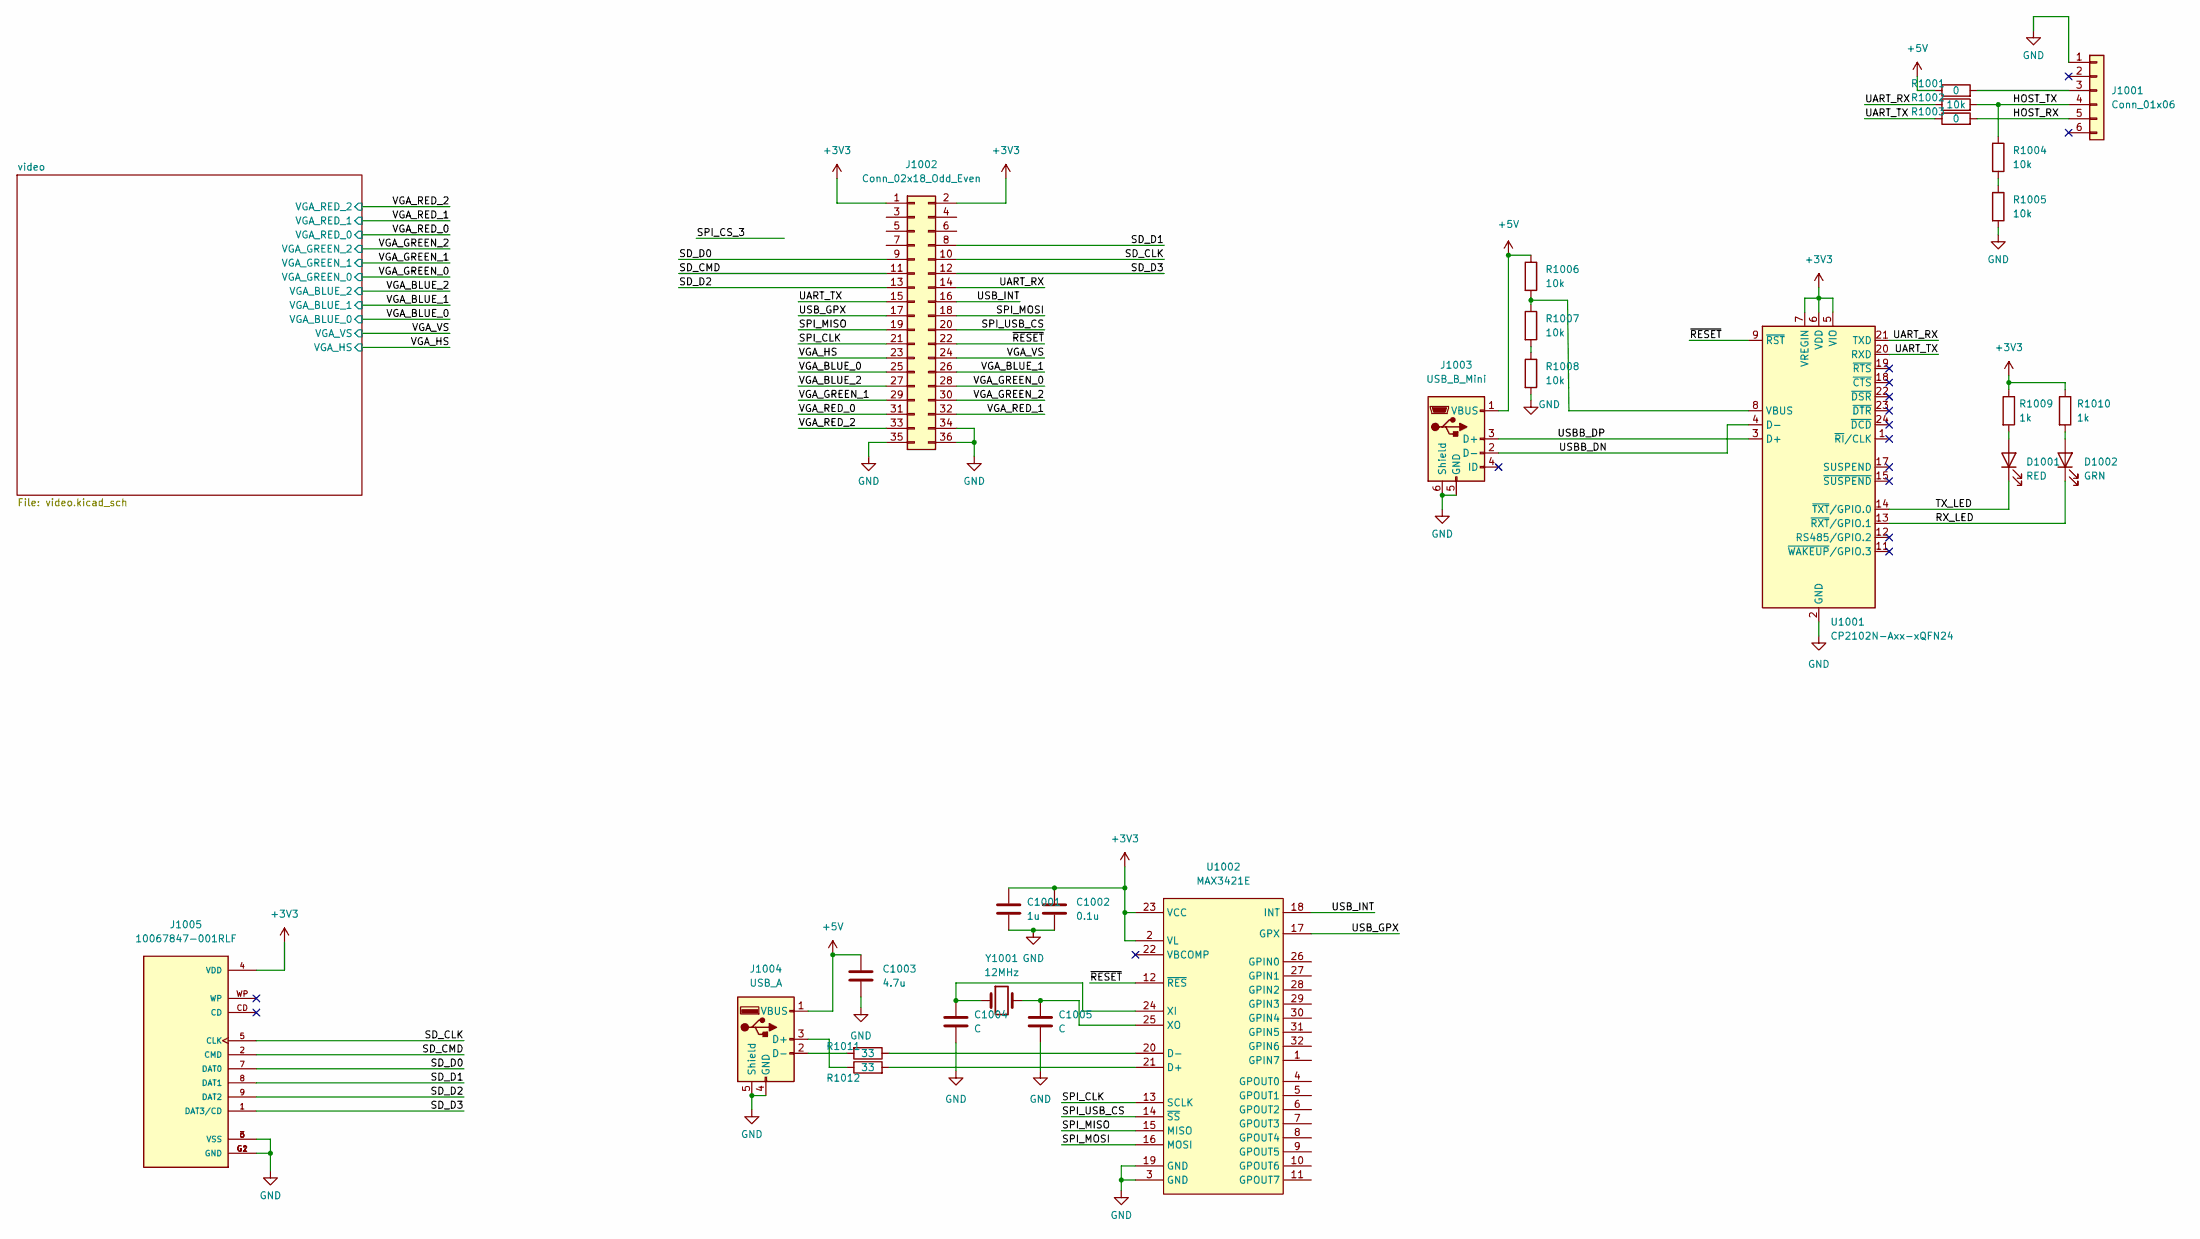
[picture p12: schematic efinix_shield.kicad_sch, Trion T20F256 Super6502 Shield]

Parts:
C1001: 1u; C_0805_2012Metric_Pad1.18x1.45mm_HandSolder
C1002: 0.1u; C_0805_2012Metric_Pad1.18x1.45mm_HandSolder
C1003: 4.7u; C_0805_2012Metric_Pad1.18x1.45mm_HandSolder
C1004, C1005: C; C_0805_2012Metric_Pad1.18x1.45mm_HandSolder
D1001: RED; LED_0805_2012Metric_Pad1.15x1.40mm_HandSolder
D1002: GRN; LED_0805_2012Metric_Pad1.15x1.40mm_HandSolder
J1001: Conn_01x06; PinHeader_1x06_P2.54mm_Vertical
J1002: Conn_02x18_Odd_Even; PinSocket_2x18_P2.54mm_Vertical
J1003: USB_B_Mini; USB_Mini-B_Wuerth_65100516121_Horizontal
J1004: USB_A; FCI_87520-0010BLF
J1005: 10067847-001RLF; AMPHENOL_10067847-001RLF; PARTREV K
R1001, R1003: 0; R_0805_2012Metric_Pad1.20x1.40mm_HandSolder
R1002, R1004, R1005, R1006, R1007, R1008: 10k; R_0805_2012Metric_Pad1.20x1.40mm_HandSolder
R1009, R1010: 1k; R_0805_2012Metric_Pad1.20x1.40mm_HandSolder
R1011, R1012: 33; R_0805_2012Metric_Pad1.20x1.40mm_HandSolder
U1001: CP2102N-Axx-xQFN24; QFN-24-1EP_4x4mm_P0.5mm_EP2.6x2.6mm
U1002: MAX3421E; LQFP-32_5x5mm_P0.5mm
Y1001: 12MHz; Crystal_HC49-U_Vertical

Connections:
+3V3: C1001.1, C1002.1, J1002.1, J1002.2, J1005.4 (VDD), R1009.1, R1010.1, U1001.5 (VIO), U1001.6 (VDD), U1001.7 (VREGIN), U1002.2 (VL), U1002.23 (VCC)
+5V: C1003.1, J1003.1 (VBUS), J1004.1 (VBUS), R1001.1, R1006.1
/HOST_RX: J1001.5, R1003.2
/HOST_TX: J1001.4, R1002.2, R1004.1
/RX_LED: D1002.1 (K), U1001.13 (~RXT/GPIO.1)
/SD_CLK: J1002.10, J1005.5 (CLK)
/SD_CMD: J1002.11, J1005.2 (CMD)
/SD_D0: J1002.9, J1005.7 (DAT0)
/SD_D1: J1002.8, J1005.8 (DAT1)
/SD_D2: J1002.13, J1005.9 (DAT2)
/SD_D3: J1002.12, J1005.1 (DAT3/CD)
/SPI_CLK: J1002.21, U1002.13 (SCLK)
/SPI_MISO: J1002.19, U1002.15 (MISO)
/SPI_MOSI: J1002.18, U1002.16 (MOSI)
/SPI_USB_CS: J1002.20, U1002.14 (~SS)
/TX_LED: D1001.1 (K), U1001.14 (~TXT/GPIO.0)
/UART_RX: J1002.14, R1002.1, U1001.21 (TXD)
/UART_TX: J1002.15, R1003.1, U1001.20 (RXD)
/USBB_DN: J1003.2 (D-), U1001.4 (D-)
/USBB_DP: J1003.3 (D+), U1001.3 (D+)
/USB_GPX: J1002.17, U1002.17 (GPX)
/USB_INT: J1002.16, U1002.18 (INT)
/VGA_BLUE_0: J1002.25; also elsewhere on the board
/VGA_BLUE_1: J1002.26; also elsewhere on the board
/VGA_BLUE_2: J1002.27; also elsewhere on the board
/VGA_GREEN_0: J1002.28; also elsewhere on the board
/VGA_GREEN_1: J1002.29; also elsewhere on the board
/VGA_GREEN_2: J1002.30; also elsewhere on the board
/VGA_HS: J1002.23; also elsewhere on the board
/VGA_RED_0: J1002.31; also elsewhere on the board
/VGA_RED_1: J1002.32; also elsewhere on the board
/VGA_RED_2: J1002.33; also elsewhere on the board
/VGA_VS: J1002.24; also elsewhere on the board
/~RESET: J1002.22, U1001.9 (~RST), U1002.12 (~RES)
GND: C1001.2, C1002.2, C1003.2, C1004.2, C1005.2, J1001.1, J1002.34, J1002.35, J1002.36, J1003.5 (GND), J1003.6 (Shield), J1004.4 (GND), J1004.5 (Shield), J1005.3 (VSS), J1005.6 (VSS), J1005.G1 (GND), J1005.G2 (GND), R1005.2, R1008.2, U1001.2 (GND), U1001.25 (GND), U1002.3 (GND), U1002.19 (GND); also elsewhere on the board
unnamed: C1004.1, U1002.24 (XI), Y1001.1
unnamed: C1005.1, U1002.25 (XO), Y1001.2
unnamed: D1001.2 (A), R1009.2
unnamed: D1002.2 (A), R1010.2
unnamed: J1001.3, R1001.2
unnamed: J1004.2 (D-), R1011.2
unnamed: J1004.3 (D+), R1012.1
unnamed: R1004.2, R1005.1
unnamed: R1006.2, R1007.1, U1001.8 (VBUS)
unnamed: R1007.2, R1008.1
unnamed: R1011.1, U1002.20 (D-)
unnamed: R1012.2, U1002.21 (D+)

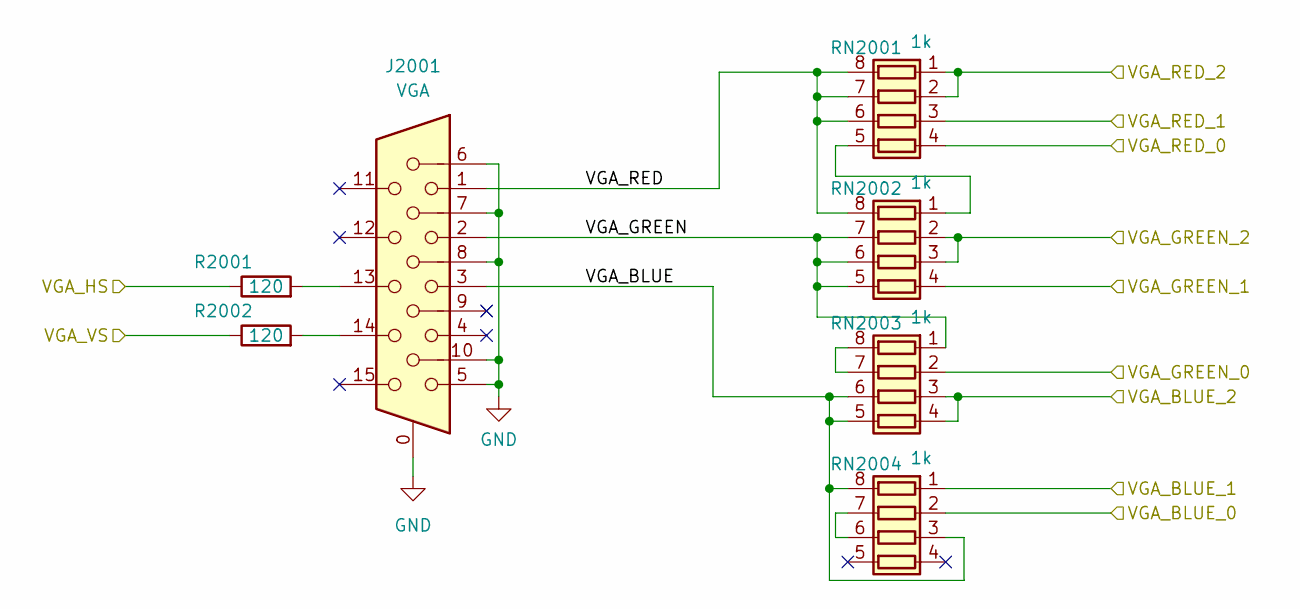
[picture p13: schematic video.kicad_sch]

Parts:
J2001: VGA; ICD15S13E4GX00LF; Part Name ICD15S13E4GX00LF
R2001, R2002: 120; R_0805_2012Metric_Pad1.20x1.40mm_HandSolder
RN2001, RN2002, RN2003, RN2004: 1k; R_Array_Concave_4x0402

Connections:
/VGA_BLUE_0: RN2004.2 (R2.1); also elsewhere on the board
/VGA_BLUE_1: RN2004.1 (R1.1); also elsewhere on the board
/VGA_BLUE_2: RN2003.3 (R3.1), RN2003.4 (R4.1); also elsewhere on the board
/VGA_GREEN_0: RN2003.2 (R2.1); also elsewhere on the board
/VGA_GREEN_1: RN2002.4 (R4.1); also elsewhere on the board
/VGA_GREEN_2: RN2002.2 (R2.1), RN2002.3 (R3.1); also elsewhere on the board
/VGA_HS: R2001.1; also elsewhere on the board
/VGA_RED_0: RN2001.4 (R4.1); also elsewhere on the board
/VGA_RED_1: RN2001.3 (R3.1); also elsewhere on the board
/VGA_RED_2: RN2001.1 (R1.1), RN2001.2 (R2.1); also elsewhere on the board
/VGA_VS: R2002.1; also elsewhere on the board
/video/VGA_BLUE: J2001.3, RN2003.5 (R4.2), RN2003.6 (R3.2), RN2004.3 (R3.1), RN2004.8 (R1.2)
/video/VGA_GREEN: J2001.2, RN2002.5 (R4.2), RN2002.6 (R3.2), RN2002.7 (R2.2), RN2003.1 (R1.1)
/video/VGA_RED: J2001.1, RN2001.6 (R3.2), RN2001.7 (R2.2), RN2001.8 (R1.2), RN2002.8 (R1.2)
GND: J2001.0, J2001.5, J2001.6, J2001.7, J2001.8, J2001.10; also elsewhere on the board
unnamed: J2001.13, R2001.2
unnamed: J2001.14, R2002.2
unnamed: RN2001.5 (R4.2), RN2002.1 (R1.1)
unnamed: RN2003.7 (R2.2), RN2003.8 (R1.2)
unnamed: RN2004.6 (R3.2), RN2004.7 (R2.2)

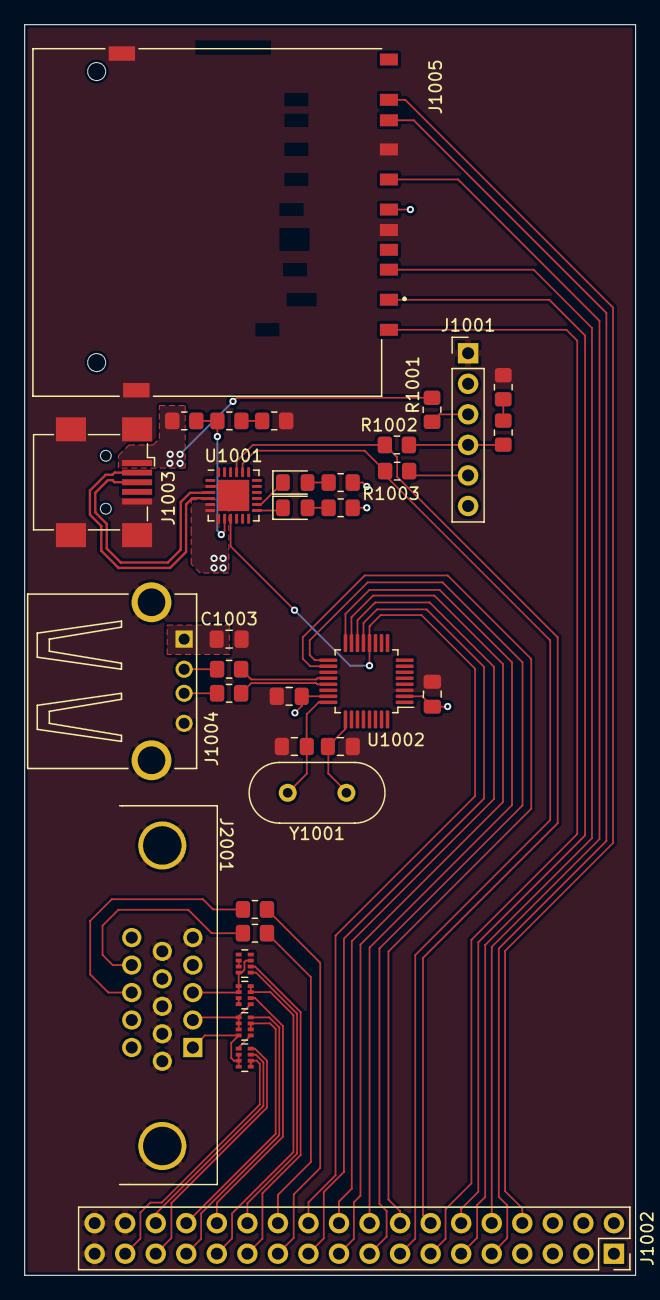
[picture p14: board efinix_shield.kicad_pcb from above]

Board: 2 copper layers, 50.8 x 104.0 mm, 34 parts (0 on the bottom side), 55 nets.

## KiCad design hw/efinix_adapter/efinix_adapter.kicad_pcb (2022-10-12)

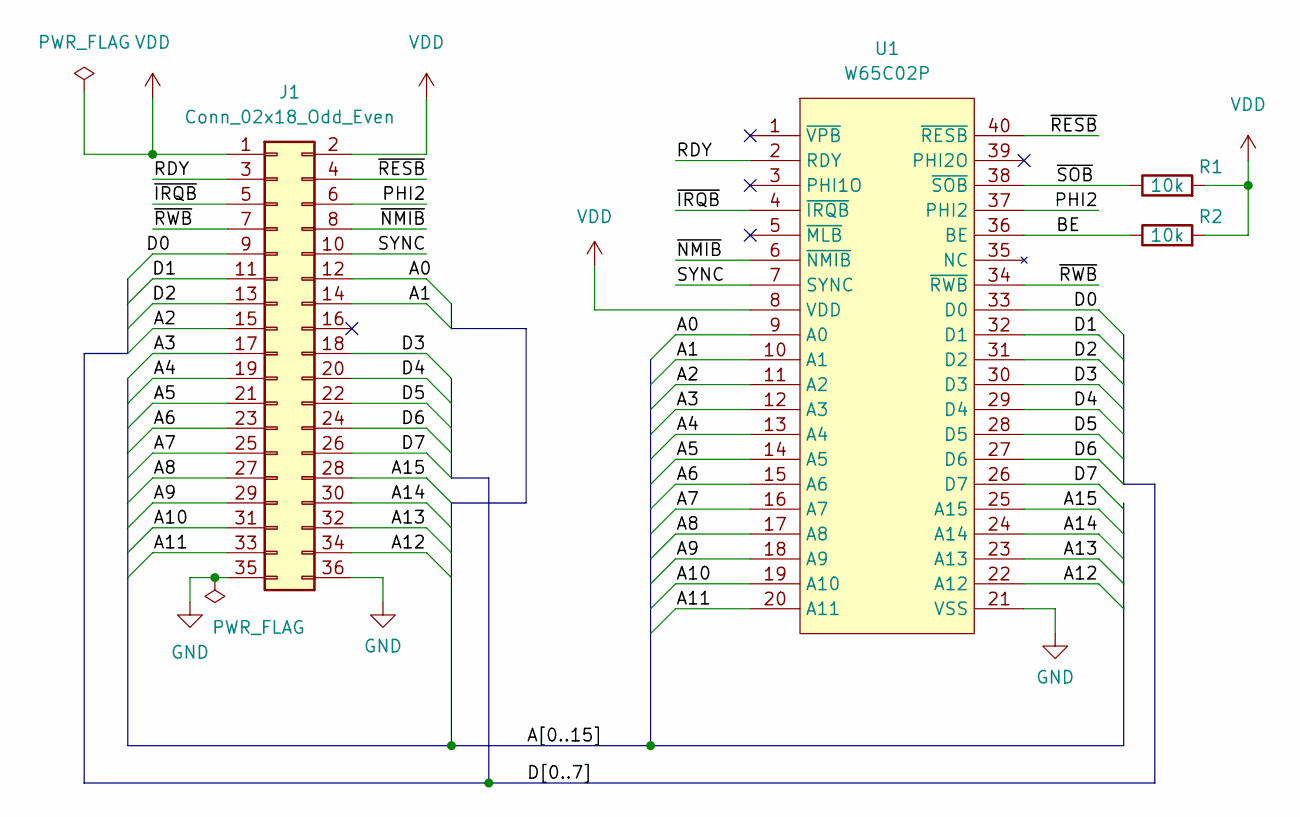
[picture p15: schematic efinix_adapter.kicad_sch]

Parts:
J1: Conn_02x18_Odd_Even; PinSocket_2x18_P2.54mm_Vertical
R1, R2: 10k; R_0603_1608Metric_Pad0.98x0.95mm_HandSolder
U1: W65C02P; DIP-40_W15.24mm_Socket_LongPads

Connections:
/A0: J1.12, U1.9 (A0)
/A1: J1.14, U1.10 (A1)
/A2: J1.15, U1.11 (A2)
/A3: J1.17, U1.12 (A3)
/A4: J1.19, U1.13 (A4)
/A5: J1.21, U1.14 (A5)
/A6: J1.23, U1.15 (A6)
/A7: J1.25, U1.16 (A7)
/A8: J1.27, U1.17 (A8)
/A9: J1.29, U1.18 (A9)
/A10: J1.31, U1.19 (A10)
/A11: J1.33, U1.20 (A11)
/A12: J1.34, U1.22 (A12)
/A13: J1.32, U1.23 (A13)
/A14: J1.30, U1.24 (A14)
/A15: J1.28, U1.25 (A15)
/BE: R2.1, U1.36 (BE)
/D0: J1.9, U1.33 (D0)
/D1: J1.11, U1.32 (D1)
/D2: J1.13, U1.31 (D2)
/D3: J1.18, U1.30 (D3)
/D4: J1.20, U1.29 (D4)
/D5: J1.22, U1.28 (D5)
/D6: J1.24, U1.27 (D6)
/D7: J1.26, U1.26 (D7)
/PHI2: J1.6, U1.37 (PHI2)
/RDY: J1.3, U1.2 (RDY)
/SYNC: J1.10, U1.7 (SYNC)
/~IRQB: J1.5, U1.4 (~IRQB)
/~NMIB: J1.8, U1.6 (~NMIB)
/~RESB: J1.4, U1.40 (~RESB)
/~RWB: J1.7, U1.34 (~RWB)
/~SOB: R1.1, U1.38 (~SOB)
GND: J1.35, J1.36, U1.21 (VSS)
VDD: J1.1, J1.2, R1.2, R2.2, U1.8 (VDD)

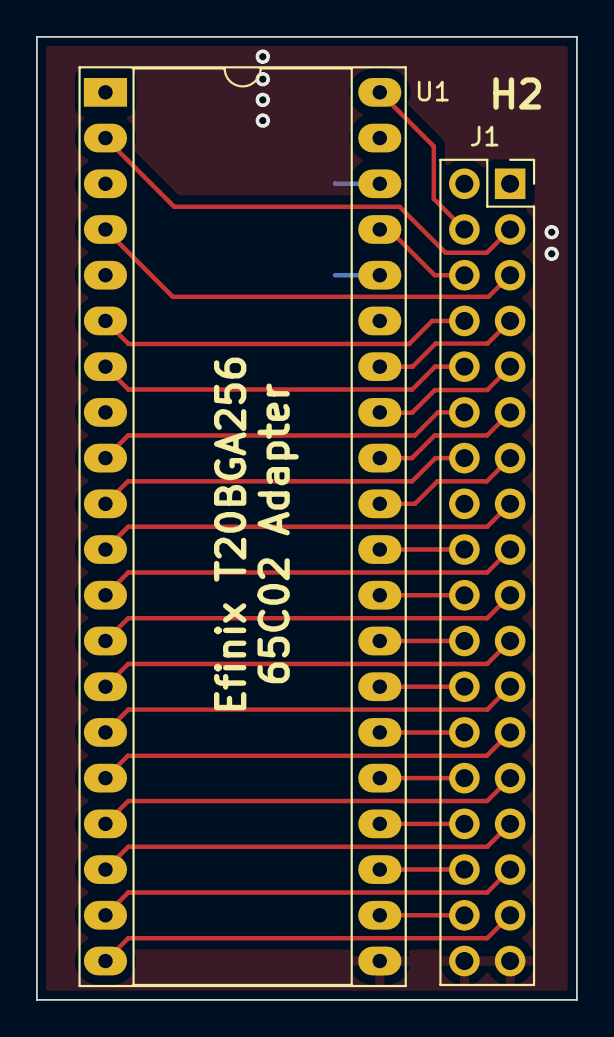
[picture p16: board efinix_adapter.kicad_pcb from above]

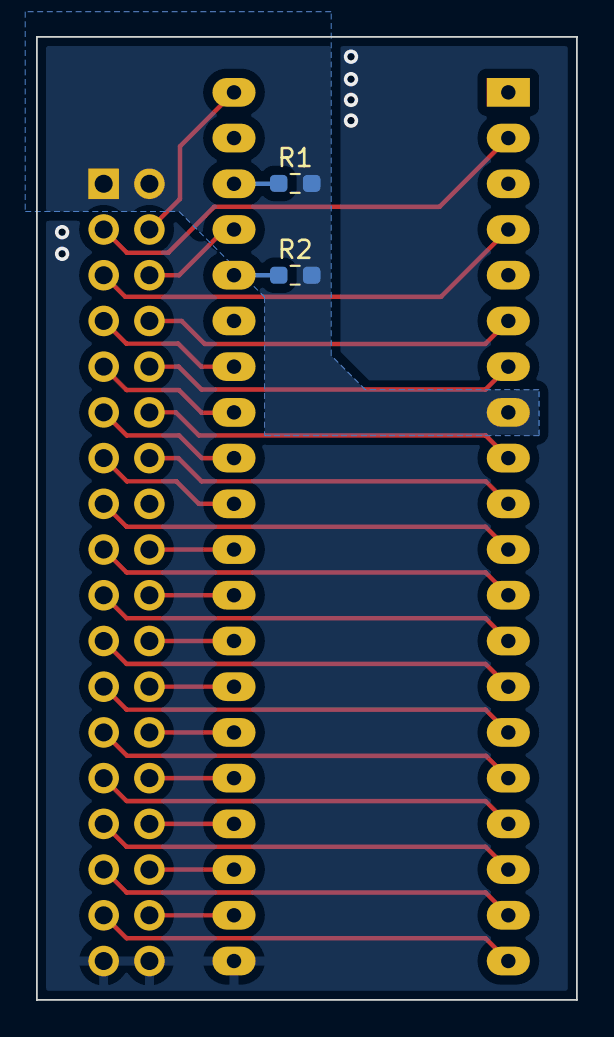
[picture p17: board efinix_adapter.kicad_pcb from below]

Board: 2 copper layers, 30.0 x 53.5 mm, 4 parts (2 on the bottom side), 35 nets.

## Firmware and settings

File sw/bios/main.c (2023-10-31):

#include <stdint.h>
#include <conio.h>
#include <string.h>
#include <stdlib.h>

#include "devices/board_io.h"
#include "devices/uart.h"
#include "devices/sd_card.h"
#include "devices/sd_print.h"

#define KERNEL_LOAD_ADDR 0xD000

//uint8_t buf[512];
uint8_t *buf = (uint8_t*)0x8000;

int main() {
    // array to hold responses
    uint8_t res[5], token;
    uint32_t addr = 0x00000000;
	uint16_t i;

	cputs("Start\n");

    // initialize sd card
    if(SD_init() != SD_SUCCESS)
    {
        cputs("Error\n");
    }
    else
    {
        cputs("Success\n");


        res[0] = SD_readSingleBlock(addr, buf, &token);
        // if no error, print buffer
        if((res[0] == 0x00) && (token == SD_START_TOKEN)) {
#ifndef RTL_SIM
            SD_printBuf(buf);
#endif
        }

        //else if error token received, print
        else if(!(token & 0xF0))
        {
            cputs("Error\n");
        } else {
            cprintf("bad token: %x\n", token);
        }

        __asm__ ("jmp (%v)", buf);
    }

    while(1) ;

}

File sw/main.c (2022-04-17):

#include <stdint.h>
#include <conio.h>
#include <string.h>

#include "board_io.h"
#include "uart.h"
#include "mapper.h"
#include "sd_card.h"
#include "fat.h"
#include "o65.h"
#include "exec.h"

uint8_t buf[512];

int main() {
	int i;
	uint16_t rca;

	clrscr();
	cprintf("Hello, world!\n");

	for (i = 0; i < 16; i++){
		//cprintf("Mapping %1xxxx to %2xxxx\n", i, i);
		mapper_write(i, i);
	}

	cprintf("Enabling Mapper\n");
	mapper_enable(1);

	sd_init();

	rca = sd_get_rca();
	cprintf("rca: %x\n", rca);

	sd_select_card(rca);

	fat_init();
	exec("/test.o65");

	cprintf("Done!\n");

	return 0;
}

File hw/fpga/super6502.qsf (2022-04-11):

# -------------------------------------------------------------------------- #
#
# Copyright (C) 2018  Intel Corporation. All rights reserved.
# Your use of Intel Corporation's design tools, logic functions 
# and other software and tools, and its AMPP partner logic 
# functions, and any output files from any of the foregoing 
# (including device programming or simulation files), and any 
# associated documentation or information are expressly subject 
# to the terms and conditions of the Intel Program License 
# Subscription Agreement, the Intel Quartus Prime License Agreement,
# the Intel FPGA IP License Agreement, or other applicable license
# agreement, including, without limitation, that your use is for
# the sole purpose of programming logic devices manufactured by
# Intel and sold by Intel or its authorized distributors.  Please
# refer to the applicable agreement for further details.
#
# -------------------------------------------------------------------------- #
#
# Quartus Prime
# Version 18.1.0 Build 625 09/12/2018 SJ Lite Edition
# Date created = 16:36:56  March 05, 2022
#
# -------------------------------------------------------------------------- #
#
# Notes:
#
# 1) The default values for assignments are stored in the file:
#		super6502_assignment_defaults.qdf
#    If this file doesn't exist, see file:
#		assignment_defaults.qdf
#
# 2) Altera recommends that you do not modify this file. This
#    file is updated automatically by the Quartus Prime software
#    and any changes you make may be lost or overwritten.
#
# -------------------------------------------------------------------------- #


set_global_assignment -name FAMILY "MAX 10"
set_global_assignment -name DEVICE 10M50DAF484C7G
set_global_assignment -name TOP_LEVEL_ENTITY super6502
set_global_assignment -name ORIGINAL_QUARTUS_VERSION 18.1.0
set_global_assignment -name PROJECT_CREATION_TIME_DATE "16:36:56  MARCH 05, 2022"
set_global_assignment -name LAST_QUARTUS_VERSION "18.1.0 Lite Edition"
set_global_assignment -name PROJECT_OUTPUT_DIRECTORY output_files
set_global_assignment -name MIN_CORE_JUNCTION_TEMP 0
set_global_assignment -name MAX_CORE_JUNCTION_TEMP 85
set_global_assignment -name ERROR_CHECK_FREQUENCY_DIVISOR 256
set_global_assignment -name EDA_SIMULATION_TOOL "ModelSim-Altera (SystemVerilog)"
set_global_assignment -name EDA_TIME_SCALE "1 ps" -section_id eda_simulation
set_global_assignment -name EDA_OUTPUT_DATA_FORMAT "SYSTEMVERILOG HDL" -section_id eda_simulation
set_global_assignment -name PARTITION_NETLIST_TYPE SOURCE -section_id Top
set_global_assignment -name PARTITION_FITTER_PRESERVATION_LEVEL PLACEMENT_AND_ROUTING -section_id Top
set_global_assignment -name PARTITION_COLOR 16764057 -section_id Top
set_location_assignment PIN_V10 -to cpu_led
set_location_assignment PIN_W10 -to cpu_vpb
set_location_assignment PIN_V9 -to cpu_resb
set_location_assignment PIN_W9 -to cpu_rdy
set_location_assignment PIN_V8 -to cpu_sob
set_location_assignment PIN_V7 -to cpu_phi2
set_location_assignment PIN_W6 -to cpu_be
set_location_assignment PIN_W5 -to cpu_rwb
set_location_assignment PIN_AA14 -to cpu_data[0]
set_location_assignment PIN_W12 -to cpu_data[1]
set_location_assignment PIN_AB12 -to cpu_data[2]
set_location_assignment PIN_AB11 -to cpu_data[3]
set_location_assignment PIN_AB10 -to cpu_data[4]
set_location_assignment PIN_AA9 -to cpu_data[5]
set_location_assignment PIN_AA8 -to cpu_data[6]
set_location_assignment PIN_AA7 -to cpu_data[7]
set_location_assignment PIN_AA6 -to cpu_addr[15]
set_location_assignment PIN_AA5 -to cpu_addr[14]
set_location_assignment PIN_AB3 -to cpu_addr[13]
set_location_assignment PIN_AB2 -to cpu_addr[12]
set_location_assignment PIN_AA2 -to cpu_addr[11]
set_location_assignment PIN_Y3 -to cpu_addr[10]
set_location_assignment PIN_Y4 -to cpu_addr[9]
set_location_assignment PIN_Y5 -to cpu_addr[8]
set_location_assignment PIN_Y6 -to cpu_addr[7]
set_location_assignment PIN_Y7 -to cpu_addr[6]
set_location_assignment PIN_Y8 -to cpu_addr[5]
set_location_assignment PIN_AA10 -to cpu_addr[4]
set_location_assignment PIN_W11 -to cpu_addr[3]
set_location_assignment PIN_Y11 -to cpu_addr[2]
set_location_assignment PIN_AB13 -to cpu_addr[1]
set_location_assignment PIN_W13 -to cpu_addr[0]
set_location_assignment PIN_AA15 -to cpu_sync
set_location_assignment PIN_V5 -to cpu_nmib
set_location_assignment PIN_W7 -to cpu_mlb
set_location_assignment PIN_W8 -to cpu_irqb
set_location_assignment PIN_C17 -to HEX0[6]
set_location_assignment PIN_D17 -to HEX0[5]
set_location_assignment PIN_E16 -to HEX0[4]
set_location_assignment PIN_C10 -to SW[0]
set_location_assignment PIN_C11 -to SW[1]
set_location_assignment PIN_D12 -to SW[2]
set_location_assignment PIN_C12 -to SW[3]
set_location_assignment PIN_A12 -to SW[4]
set_location_assignment PIN_B12 -to SW[5]
set_location_assignment PIN_A13 -to SW[6]
set_location_assignment PIN_A14 -to SW[7]
set_location_assignment PIN_B14 -to SW[8]
set_location_assignment PIN_F15 -to SW[9]
set_location_assignment PIN_A8 -to LED[0]
set_location_assignment PIN_A9 -to LED[1]
set_location_assignment PIN_A10 -to LED[2]
set_location_assignment PIN_B10 -to LED[3]
set_location_assignment PIN_D13 -to LED[4]
set_location_assignment PIN_C13 -to LED[5]
set_location_assignment PIN_E14 -to LED[6]
set_location_assignment PIN_D14 -to LED[7]
set_location_assignment PIN_A11 -to LED[8]
set_location_assignment PIN_B11 -to LED[9]
set_location_assignment PIN_F21 -to HEX3[0]
set_location_assignment PIN_E22 -to HEX3[1]
set_location_assignment PIN_E21 -to HEX3[2]
set_location_assignment PIN_C19 -to HEX3[3]
set_location_assignment PIN_C20 -to HEX3[4]
set_location_assignment PIN_D19 -to HEX3[5]
set_location_assignment PIN_E17 -to HEX3[6]
set_location_assignment PIN_B20 -to HEX2[0]
set_location_assignment PIN_A20 -to HEX2[1]
set_location_assignment PIN_B19 -to HEX2[2]
set_location_assignment PIN_A21 -to HEX2[3]
set_location_assignment PIN_B21 -to HEX2[4]
set_location_assignment PIN_C22 -to HEX2[5]
set_location_assignment PIN_B22 -to HEX2[6]
set_location_assignment PIN_C18 -to HEX1[0]
set_location_assignment PIN_D18 -to HEX1[1]
set_location_assignment PIN_E18 -to HEX1[2]
set_location_assignment PIN_B16 -to HEX1[3]
set_location_assignment PIN_A17 -to HEX1[4]
set_location_assignment PIN_A18 -to HEX1[5]
set_location_assignment PIN_B17 -to HEX1[6]
set_location_assignment PIN_C14 -to HEX0[0]
set_location_assignment PIN_E15 -to HEX0[1]
set_location_assignment PIN_C15 -to HEX0[2]
set_location_assignment PIN_C16 -to HEX0[3]
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

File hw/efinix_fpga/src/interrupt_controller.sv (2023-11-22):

module interrupt_controller 
#(
    parameter N_INTERRUPTS = 128
)(
    input clk,
    input reset,
    input [7:0] i_data,
    output logic [7:0] o_data,
    input addr,
    input cs,
    input rwb,

    input [N_INTERRUPTS-1:0] int_in,
    output logic int_out
);

logic w_enable_write;
logic [7:0] w_enable_data;
logic [N_INTERRUPTS-1:0] w_enable_full_data;

logic [N_INTERRUPTS-1:0] int_in_d1;

logic [4:0] w_byte_sel;

logic [7:0] irq_val;

byte_sel_register #(
    .DATA_WIDTH(8),
    .ADDR_WIDTH(N_INTERRUPTS/8)
) reg_enable (
    .i_clk(~clk),
    .i_reset(reset),
    .i_write(w_enable_write),
    .i_byte_sel(w_byte_sel),
    .i_data(i_data),
    .o_data(w_enable_data),
    .o_full_data(w_enable_full_data)
);

logic we, re;

assign we = cs & ~rwb;
assign re = cs & rwb;

logic [N_INTERRUPTS-1:0] int_masked;
assign int_masked = int_in & w_enable_full_data;


logic w_type_write;
logic [7:0] w_type_data;
logic [N_INTERRUPTS-1:0] w_type_full_data;

byte_sel_register #(
    .DATA_WIDTH(8),
    .ADDR_WIDTH(N_INTERRUPTS/8)
) reg_type (
    .i_clk(~clk),
    .i_reset(reset),
    .i_write(w_type_write),
    .i_byte_sel(w_byte_sel),
    .i_data(i_data),
    .o_data(w_type_data),
    .o_full_data(w_type_full_data)
);

logic [7:0] cmd, cmd_next;

logic w_eoi;

logic [N_INTERRUPTS-1:0] r_int, r_int_next;

always_comb begin
    w_eoi = 0;

    if (addr == '0 && we) begin
        cmd_next = i_data;
    end else begin
        cmd_next = cmd;
    end


    w_type_write = '0;
    w_enable_write = '0;

    if (addr == '1) begin
        unique casez (cmd)
            8'b000?????: begin
                o_data = irq_val;
            end

            8'b001?????: begin
                w_enable_write = we;
                w_byte_sel = cmd[4:0];
                o_data = w_enable_data;
            end

            8'b010?????: begin
                w_type_write = we;
                w_byte_sel = cmd[4:0];
                o_data = w_type_data;
            end

            8'hff: begin
                // Kind of dumb, still requires a data write
                w_eoi = i_data[0] & we;
            end
        endcase
    end

    int_out = |r_int;

    irq_val = 8'hff;
    for (int i = N_INTERRUPTS-1; i >= 0; i--) begin
        if (r_int[i] == 1) begin
            irq_val = i;
        end
    end

    for (int i = 0; i < N_INTERRUPTS; i++) begin
        case (w_type_full_data[i])
            0: begin    // Edge triggered
                if (w_eoi && i == irq_val) begin
                    r_int_next[i] = 0;
                end else begin
                    r_int_next[i] = (~int_in_d1[i] & int_masked[i]) | r_int[i];
                end
            end

            1: begin    // Level Triggered
                // If we are trying to clear this interrupt but it is still active,
                // then we don't actually want to clear it.
                if (w_eoi && i == irq_val) begin
                    r_int_next[i] = int_masked[i];
                end else begin
                    r_int_next[i] = r_int[i] | int_masked[i];
                end
            end
        endcase
    end
end

always_ff @(negedge clk) begin
    if (reset) begin
        r_int <= '0;
        cmd <= '0;
        int_in_d1 <= '0;
    end else begin
        r_int <= r_int_next;
        cmd <= cmd_next;
        int_in_d1 <= int_in;
    end
end

endmodule

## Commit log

2022-03-05 Create project
    [board.kicad_pcb, board.kicad_sch]
2022-03-05 Create board
    [board.kicad_pcb, board.kicad_sch]
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2022-03-08 Fix ground plane not connected
    [board.kicad_pcb]
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2022-03-10 Fix spi bug
    Was reading a value from x, shifting it, but then not writing it back.
    This caused an infinite loop as it would never move on from the MSB.
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2022-03-10 Change spi_write_byte to spi_byte
    the SPI module reads and writes at the same time. If you don't want to
    write a value, then write all zeros or whatever the device you are
    communicating with wants.
2022-03-10 Remove spi_word and replace with spi_deselect
    Since the goal is to have the MAX3421E working, which uses multiple 8
    bit transfers, we should support multiple 8 bit transfers instead of
    trying to use 16 bit transfers.
    When using spi_byte(), the device is automatically selected. After you
    have made as many transfers as you want, you must deselect the device
    with spi_deselect().
2022-03-10 Add USB code
    Adds the usb code that we got in ECE 385. It will not work now, and
    parts that involve the timer are disabled. It does compile though, with
    a few warnings.
    The goal will be to add USB MSD support, which is not actually given to
    us so I will have to do myself or find some other code to base it off
    of.
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2022-03-12 Get the FPGA part working
    This changes some of the clocks, fixes a bug in the seven segment stuff.
    [stp1.stp]
2022-03-12 Update bootstrap code
    Was missing some things like initializing the stack pointer, clearing
    BSS, and things like that
    [main.c]
2022-03-13 Don't track signaltap
    [stp1.stp]
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2022-03-13 Add driver for hex digits
    This only includes the method to set the pairs of displays individually.
    The functions to write a single 16 or 32 bit value have not been
    implemented yet, nor has the mask function.
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2022-03-14 Add basic UART device
    So far the device only transmits the ASCII set on repeat, but will
    become fully featured later.
2022-03-14 Refactor uart.sv to better allow cpu control
    Added new signal tx_flag, which indicates whether the transmitter is
    ready for new data.
    Added status register, which when read will return the tx_flag bit, as
    well as others that can be implemented.
    Added new state IDLE, which resets the TX flag and allows new data to be
    written.
    Added code to allow for different baud rates, though it is still fixed
    currently.
2022-03-14 Add write and puts tasks to the uart testbench
    The write task will transmit a single byte, the puts task will transmit
    a string of length n. These do not do any verification, you still have
    to look at the output.
2022-03-14 Add basic UART driver
    This didn't have a chance to get tested so I hope it works.
    There is not fancy stuff here, just write to the register and wait till
    it is done.
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2022-03-14 Integrate uart controller into top level module
    Adds new chip select for the UART, and a new entry in the data_out mux
    for the UART.
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2022-03-14 Update cs_testbench.sv
    Add uart_cs and fix error messages
2022-03-14 Connect Button 1 to cpu_irqb
    A maskable interrupt can be generated by pressing button 1, the reset
    button remains button 0.
    [super6502.qsf]
2022-03-14 Add interrupt handlers and redo vector locations
    Most of these are taken from
    https://cc65.github.io/doc/customizing.html, but modified to suit this
    setup.
2022-03-14 Add irq status register
    Upon receiving an interrupt, the corresponding bit in the interrupt
    status register will be set and an IRQ will be raised for the CPU. The
    cpu can then respond to the interrupt and clear the interrupt by writing
    back to the interrupt status register.
2022-03-14 Exclude vectors from list of test objects
    We do not need this, since there are no interrupts during tests.
2022-03-14 Implement interrupt status register
    Upon an interrupt, you can read from the interrupt status register to
    see what caused the interrupt.
2022-03-14 Add irq_set_status
    irq_set_status can be used to clear the irq status bit so that the
    interrupt will stop occuring.
2022-03-14 Add UART interrupts
    Currently an interrupt is triggered any time there is any activity on
    the UART_RXD line, but later it will only trigger once there is data
    ready to be read.
2022-03-14 Add receive logic to UART
    The UART has a receive buffer which will fill up when it receives bytes.
    Once the buffer is full, it raises the RX flag until the value is read
    by the cpu.
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2022-03-17 Add SDRAM controller (controller)
    Turns out there are some issues with holding the chip select for the
    SDRAM controller high for too long, so there is a simple 2-state fsm
    which ensures that the chip select is only held for 1 clock cycle for
    writes and for as long as it takes to read the data from sdram for
    reads.
    [super6502.qsf]
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2022-03-18 Add board-io, replace sevenseg in sw
    [main.c]
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2022-04-05 Add memory mapper.
    Based on the 74ls610 but with some slight changes.
    The memory mapper works by having a 16x12 ram array. The top 4 bits of
    the address are used to index into this array, and the resulting word
    replaces those top 4 bits. In this way, a 16 bit address is replaced
    with a 24 bit address.
    As of now there is no way to write 12 bit values though, so currently
    we are using 20 bit addresses.
    There is a chip select line that allows you to write into the ram array,
    and another chip select that allows you to write to the control word.
    Currently the control word is just a single bit, the enable bit.
    When not enabled, the 4 index bits are passed straight through, and the higher
    bits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
    [super6502.qsf]
2022-04-07 Identity map memory upon reset
    Upon reset the mapper is set to identity map and then enabled.
    [main.c]
2022-04-10 Fix state transitions with regard to clock
    The SD card expects data to transition on falling edges and be stable on
    rising edges.
    Additionally, writes from the CPU were not handled with correct timing.
    Now, there is an extra state when writing to the command register so
    that the command is properly latched before the CRC is calculated.
    [sd_controller.sv]
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2022-04-11 Add read flag to sd controller
    Read flag is set when the sd controller reads response data in from the
    sd card. When the cpu reads from the controller, the flag is reset.
    This flag does not trigger an interrupt, it mmust be polled.
    [sd_controller.sv]
2022-04-11 Fix some warnings
    Adds some missing cases, length specifiers.
    [sd_controller.sv]
2022-04-14 Reset bit count upon entering RXDATA
    The but count should be set to 7 when entering RXDATA. previously it was
    not reset or left at 0, which caused the first byte to only have the lsb
    set and all other bits to be read incorrectly.
    [sd_controller.sv]
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2022-04-18 Create boot environment
    The boot environment will read the boot sector from the sd card, verify
    that it has the boot signature at the end, then jump to the start of it.
    From there, there should be a bootloader written to the boot segment
    that can handle the rest.
    It might be tight to fit everything into the boot sector but do remember
    that you do not have to initialize or select the sd card, and those
    functions take up a lot of space.
    [sd_card.c]
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2022-04-19 Replace bios with bootloader, don't use bootsector
    Instead of using the bootsector to load a bootloader, just put the
    bootloader in the ROM and call it a day. It looks for a file on the SD
    card in the root directory named `kernel.bin` and loads it into memory.
    This is not a perfect solution, as the kernel will grow larger and the
    kernel load address will have to change. At this point I could add back
    the bootloader, but that is for later.
    Also the bootloader is just a copy of the kernel, so that can be trimmed
    down a lot.
    [main.c, sd_card.c]
2022-10-04 Throw everything up
    I think that previously, I had not actually commited any of this to git.
    This adds all of the new effinix stuff that I had been working on for
    months.
    The gist of all of this is that the intel fpga is expensive and does not
    exist, whereas the effinix ones are not as expensive and more existant.
    This redoes the project to use the dev board, as well as a custom board
    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
    [efinix_shield.kicad_pcb, efinix_shield.kicad_sch]
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2022-10-12 Create Efinix Adapter
    Split the project into two parts, the adapter will connect the cpu
    directly to the FPGA, and the shield will house all of the peripherals.
    I will get the adapter first so that I can get things like sdram
    working first, and then make the shield with things like SD card, USB,
    maybe even ethernet and VGA. Basically anthing since it's connected to
    an FPGA.
    [efinix_adapter.kicad_pcb, efinix_adapter.kicad_sch]
2022-10-12 Redo shield, removing FPGA
    Don't have the FPGA on the shield, just have it be a board that plugs
    into the FPGA.
    Don't mind the component and footprint choices yet, I still need to
    figure out exactly which parts to use.
    [efinix_shield.kicad_pcb, efinix_shield.kicad_sch, fpga.kicad_sch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]
2022-10-12 Change drill output folder
    [efinix_adapter.kicad_pcb]
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2022-12-20 Start over pretty much.
    [efinix_shield.kicad_sch]
2022-12-20 Get block rom kind of working
    [mem_config.txt]
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2022-12-22 throw some stuff on.
    This will have to be changed, some things like the VGA connector will
    not work because they will interfere with the cpu adapter.
    It may be worth thinking about making these smaller and not including
    the ethernet for example, since that will not come for a while.
    The only things we really need to start are the SD card and serial port.
    [efinix_shield.kicad_pcb, efinix_shield.kicad_sch, video.kicad_sch]
2022-12-23 Start work on simpler board
    [efinix_shield.kicad_pcb, efinix_shield.kicad_sch, video.kicad_sch]
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2022-12-30 Finish routing sd card slot, update gitignore
    [efinix_shield.kicad_pcb, efinix_shield.kicad_sch]
2022-12-30 Make adapter for 385 board
    [385_adapter.kicad_pcb, 385_adapter.kicad_sch]
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2023-01-10 Add text labels to arduino pins
    I finally found the schematics for the 385 board so now there can be
    labels for what the pins actually do.
    [385_adapter.kicad_sch]
2023-01-10 Add labels on fpga side
    [385_adapter.kicad_sch]
2023-01-10 Add labels for sd mode
    [385_adapter.kicad_sch]
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2023-01-13 Change test program to use correct args
    Seems to work, when you run the test program it resets the card and
    sends the voltage and test pattern, and it does receive a response from
    the card.
2023-01-13 Change to simpler rom
    [mem_config.txt]
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2023-07-24 Consolidate resp3 and resp7, fix stack issue
    wasn't pushing res to stack, which makes stack pointer wrong
    [sd_card.c]
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2023-08-09 Link bootloader with bios to get access to symbols
    By doing this we don't need to call bios functions, we can just jsr
    directly to the addresses. This does mean that everytime the bios
    changes the bootloader has to change, but ideally all the bootloader
    does is load the bios and then get remapped out of memory. Any important
    drivers like file system can be loaded from the bootloader.
    This also means that the runtime functions are located in the bios for
    the bootloader, so the rom will have to stay mapped in until the kernel
    is started, at which point it will have its own runtime and the rom and
    bootloader are no longer needed.
    [main.c]
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2023-09-19 Resolve "Organize Project Better"
    [interrupt_controller.sv, sd_controller.sv]
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2023-09-28 Fix uart status multiple drivers
2023-09-30 Resolve "Use dependencies instead of makefile chaining"
2023-10-26 Don't print buf, it takes too long
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2023-11-16 Fix makefile, fix how interrupts are triggered
    [interrupt_controller.sv]
2023-11-16 Fix level triggered test, add to ci
    [interrupt_controller.sv]
2023-11-17 Fix edge trigger, reorganize testbench
    [interrupt_controller.sv]
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2023-11-19 Fix irq code tb now that interrupts are used
2023-11-20 RTC: Fix threshold/irq_threshold initialization
    Also throw some newlines in the kernel print messages.
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2023-11-26 Add parts list
    [board.kicad_pcb, board.kicad_sch, parts_list.xlsx]
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2023-11-27 Create project, set env vars
    [board.kicad_pcb, board.kicad_sch, t20_pinout-v3.4.xlsx]
2023-11-27 Create schematic heirarchy
    [board.kicad_pcb, board.kicad_sch, board_io.kicad_sch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]
2023-11-27 Add wires to fpga block (but don't connect them)
    [board.kicad_pcb, board.kicad_sch, cpu.kicad_sch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]
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2023-12-06 Get something working with read
    It is not reading offset correctly
    [main.c]
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2023-12-09 Add fixes for multiple sectors per cluster
    [main.c]
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

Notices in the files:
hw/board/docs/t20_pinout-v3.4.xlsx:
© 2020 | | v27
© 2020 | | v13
